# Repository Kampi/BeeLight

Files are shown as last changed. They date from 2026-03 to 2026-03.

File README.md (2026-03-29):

# BeeLight - Zigbee based light & environment sensor for Home Automation





## Table of Contents

- [BeeLight - Zigbee based light \& environment sensor for Home Automation](#beelight---zigbee-based-light--environment-sensor-for-home-automation)
  - [Table of Contents](#table-of-contents)
  - [About](#about)
    - [Technical features](#technical-features)
  - [Before you start](#before-you-start)
    - [PCB](#pcb)
    - [Firmware](#firmware)
      - [Build the firmware](#build-the-firmware)
      - [Flash the firmware](#flash-the-firmware)
      - [Generate the production config for the device](#generate-the-production-config-for-the-device)
        - [Using west](#using-west)
        - [Using the command line](#using-the-command-line)
    - [Housing](#housing)
    - [Zigbee](#zigbee)
      - [Standard clusters](#standard-clusters)
      - [Custom cluster](#custom-cluster)
      - [Zigbee Dongle](#zigbee-dongle)
      - [Install the device to Zigbee2MQTT](#install-the-device-to-zigbee2mqtt)
      - [Using the NCS Zigbee Shell](#using-the-ncs-zigbee-shell)
  - [Directory structure](#directory-structure)
  - [Resources](#resources)
  - [Maintainer](#maintainer)

## About

Open-Source Zigbee-based light and environmental sensor with [Zigbee2MQTT](https://www.zigbee2mqtt.io/) support for your Home Automation (e.g., Home Assistant).

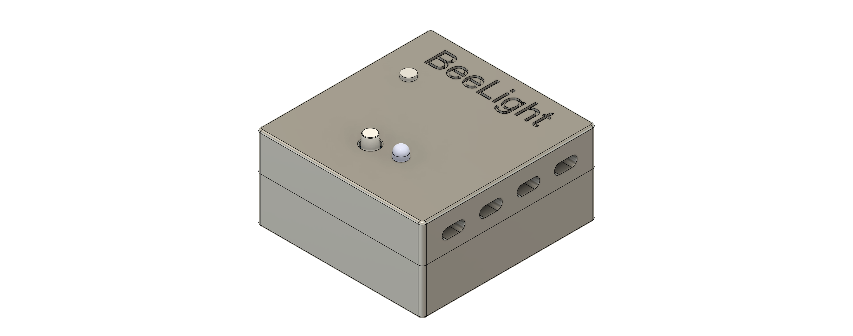
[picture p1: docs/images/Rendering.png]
Rendering


### Technical features

- Cutting-edge MCU module with an nRF54L, running Zephyr
- Powered by a single coin cell
- Can measure
  - Temperature
  - Humidity
  - Pressure
  - IAQ
  - CO2 equivalent
  - VOC equivalent
  - Light intensity
  - Battery voltage
- Small housing (40x42x20 mm)
- Very basic electronic → Can be assembled by hand very easily
- Zigbee2MQTT compatibility

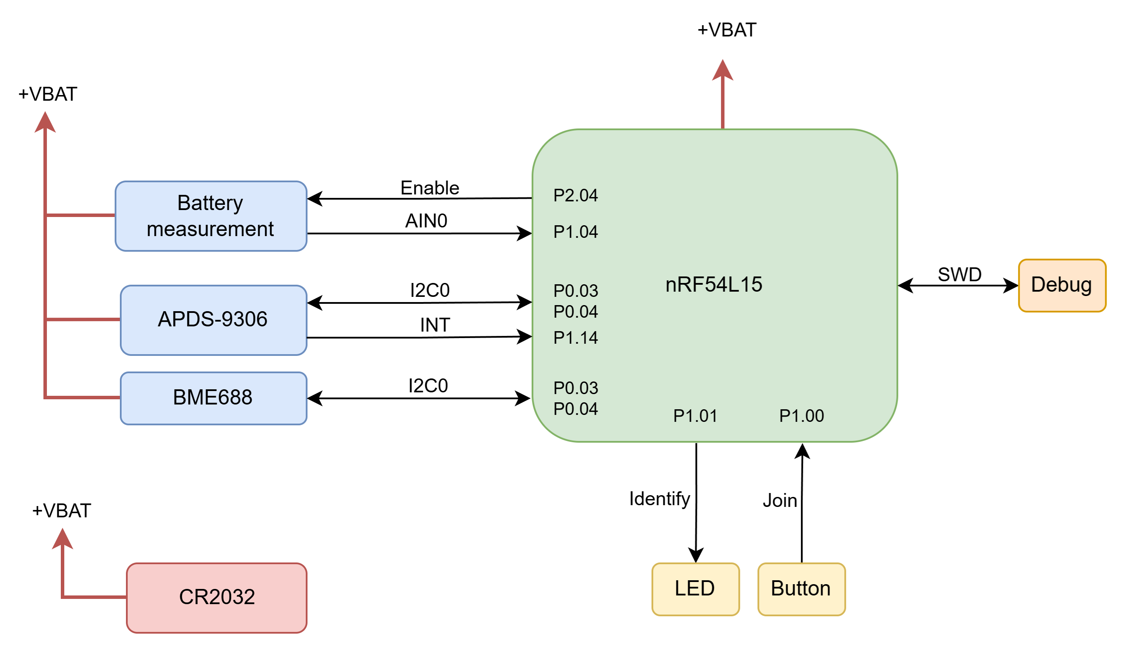
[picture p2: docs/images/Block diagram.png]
Block diagram


## Before you start

The project directory contains the hardware as a [KiCad 9](https://www.kicad.org/download/) project, the firmware and the Zigbee2MQTT configuration. You can check it out with Git:

```sh
git clone https://github.com/Kampi/BeeLight
cd BeeLight
git submodule update --init --recursive
cd firmware/app
west init -l .
west update
```

You also need [nrfutil](https://www.nordicsemi.com/Products/Development-tools/nRF-Util) and the `nrf5sdk-tools` to flash the production configuration to the sensor. First install `nrfutil` and then run the following command to install the SDK tools:

```sh
nrfutil install nrf5sdk-tools
```

### PCB

The project uses [Kibot](https://github.com/INTI-CMNB/KiBot) to automatically generate all required output data. After installing it you can execute the following command to run it:

```sh
cd hardware
./kibot-launch.sh
```

As an alternative you can run it via CI/CD in GitHub.

> **NOTE**
> You have to provide a Mouser API key with a variable called `MOUSER_KEY` to make use of the KiCost feature in the Kibot job.
>
> **NOTE**
> The programming connector is optional and can be left out or unsoldered after flashing the device.

### Firmware

#### Build the firmware

The firmware can be built with the following command:

```sh
cd firmware/app
west build --build-dir build . --pristine --board beelight@1/nrf54l15/cpuapp -- -DNCS_TOOLCHAIN_VERSION=NONE -DEXTRA_CONF_FILE=config/debug.conf -DBOARD_ROOT=.
```

You also need a Zigbee network to test and integrate the device. I use [Zigbee2MQTT](https://www.zigbee2mqtt.io/) running on a Raspberry Pi which allows me to connect my Zigbee network with my Home Automation.

> **NOTE**
> I do not support other Zigbee networks (like [ZHA](https://www.home-assistant.io/integrations/zha/)). The Zigbee standard allows you to connect the device with all other networks but I can't deliver a functional integration for these networks. You have to do it on your own!

#### Flash the firmware

After building the firmware you can run

```sh
west flash
```

to flash the firmware into the module.

> **NOTE**
> For some reason the current consumption stays high after flashing. I recommend a complete power cycle after flashing to make sure the device is consuming the lowest current possible.

#### Generate the production config for the device

##### Using west

You can run the command `west upload_config` to build and upload your configuration to the device automatically.

##### Using the command line

You must flash a production config to the device, before you can use it with Zigbee. You can either use the prebuilt config from the project or adjust it according to your needs.

```sh
nrfutil nrf5sdk-tools zigbee production_config zigbee_config.yml zigbee_config.hex --offset 0x17a000
nrfjprog --program zigbee_config.hex --verify
```

> **NOTE**
> The offset `0x17a000` is taken from the `PM_ZBOSS_PRODUCT_CONFIG_OFFSET` macro in `build/<app>/zephyr/include/generated/pm_config.h`. Also make sure to change `extended_address` in the Zigbee
> configuration file if you use more than one device!

### Housing

The housing is optimized for 3D printing and needs ~12 g of filament (PLA). You can find all the needed files in the `3d-printing` directory of this project.

### Zigbee

The device uses different standard and custom cluster to report the data to the network.

#### Standard clusters

| Cluster | ID |
| --- | -- |
| Temperature | 0x0402 |
| Pressure | 0x0403 |
| Rel. Humidity | 0x0405 |
| Light | 0x0400 |

#### Custom cluster

The device uses three custom cluster to report `IAQ`, `VOC` and `CO2` to the network. Both clusters have three attributes for `value`, `min_value`, `max_value` and `tolerance`.

| Cluster | ID |
| --- | -- |
| IAQ | 0x1A0A |
| VOC | 0x1A0B |
| CO2 | 0x1A0C |

| Attribute | ID |
| --- | -- |
| Value | 0x0000 |
| Min. Value | 0x0001 |
| Max. Value | 0x0002 |
| Tolerance | 0x0003 |

#### Zigbee Dongle

Make sure to use a Zigbee 3 compatible dongle like [SONOFF ZBDongle-E](https://sonoff.tech/product/gateway-and-sensors/sonoff-zigbee-3-0-usb-dongle-plus-e/) and update the firmware to the latest version to prevent issues. You can follow [this](https://dongle.sonoff.tech/sonoff-dongle-flasher/) guide if you use a SONOFF dongle.

#### Install the device to Zigbee2MQTT

> **NOTE**
> Because it's not possible to use custom clusters with Zigbee2MQTT easily, you must adjust the application directly to use the sensor. Please take a look into the directory `z2m/data/external_converters/example` if you want to check how the modified files look like.

1. Download and install [Zigbee2MQTT](https://github.com/zigbee2mqtt/hassio-zigbee2mqtt)
2. Copy the external converter from `z2m/data_external_converters` to the `data` directory of your `Zigbee2MQTT` installation
3. Switch into the directory `.../zigbee2mqtt/node_modules/zigbee-herdsman/dist/zspec/zcl/definition` and open `cluster.js` and add the following code to `exports.Clusters`

```ts
...
    msBeelightIAQ: {
        ID: 6666,
        attributes: {
            measuredValue: { ID: 0, type: enums_1.DataType.UINT16 },
            minMeasuredValue: { ID: 1, type: enums_1.DataType.UINT16 },
            maxMeasuredValue: { ID: 2, type: enums_1.DataType.UINT16 },
            tolerance: { ID: 3, type: enums_1.DataType.UINT8 },
        },
        commands: {},
        commandsResponse: {},
    },
    msBeelightVOC: {
        ID: 6667,
        attributes: {
            measuredValue: { ID: 0, type: enums_1.DataType.UINT16 },
            minMeasuredValue: { ID: 1, type: enums_1.DataType.UINT16 },
            maxMeasuredValue: { ID: 2, type: enums_1.DataType.UINT16 },
            tolerance: { ID: 3, type: enums_1.DataType.UINT8 },
        },
        commands: {},
        commandsResponse: {},
    },
    msBeelightCO2: {
        ID: 6668,
        attributes: {
            measuredValue: { ID: 0, type: enums_1.DataType.UINT16 },
            minMeasuredValue: { ID: 1, type: enums_1.DataType.UINT16 },
            maxMeasuredValue: { ID: 2, type: enums_1.DataType.UINT16 },
            tolerance: { ID: 3, type: enums_1.DataType.UINT8 },
        },
        commands: {},
        commandsResponse: {},
    },
...
```

4. Save the file
5. Switch to `.../zigbee2mqtt/node_modules/zigbee-herdsman-converters/dist/lib`
6. Open the file `modernExtend.js` and add the following cluster to the end of the list at the end of the file:
7. Add

```js
...
exports.BeeLight_iaq = BeeLight_iaq;
exports.BeeLight_co2 = BeeLight_co2;
exports.BeeLight_voc = BeeLight_voc;
...
```

8. Extend the following section

```js
// #region Measurement and Sensing
function BeeLight_iaq(args = {}) {
    return numeric({
        name: "BeeLight_iaq",
        cluster: "msBeelightIAQ",
        attribute: "measuredValue",
        reporting: { min: "5_MINUTES", max: "1_HOUR", change: 10 },
        description: "Measured IAQ value",
        unit: "",
        scale: 1,
        access: "STATE_GET",
        ...args,
    });
}
function BeeLight_co2(args = {}) {
    return numeric({
        name: "BeeLight_co2",
        cluster: "msBeelightCO2",
        attribute: "measuredValue",
        reporting: { min: "5_MINUTES", max: "1_HOUR", change: 10 },
        description: "Measured CO2 value",
        unit: "ppm",
        scale: 1,
        access: "STATE_GET",
        ...args,
    });
}
function BeeLight_voc(args = {}) {
    return numeric({
        name: "BeeLight_voc",
        cluster: "msBeelightVOC",
        attribute: "measuredValue",
        reporting: { min: "5_MINUTES", max: "1_HOUR", change: 10 },
        description: "Measured VOC value",
        unit: "ppm",
        scale: 1,
        access: "STATE_GET",
        ...args,
    });
}
...
```

9. Save the file
10. Restart Zigbee2MQTT

The device can now be connected to your Zigbee network and with this to your Home Assistant.

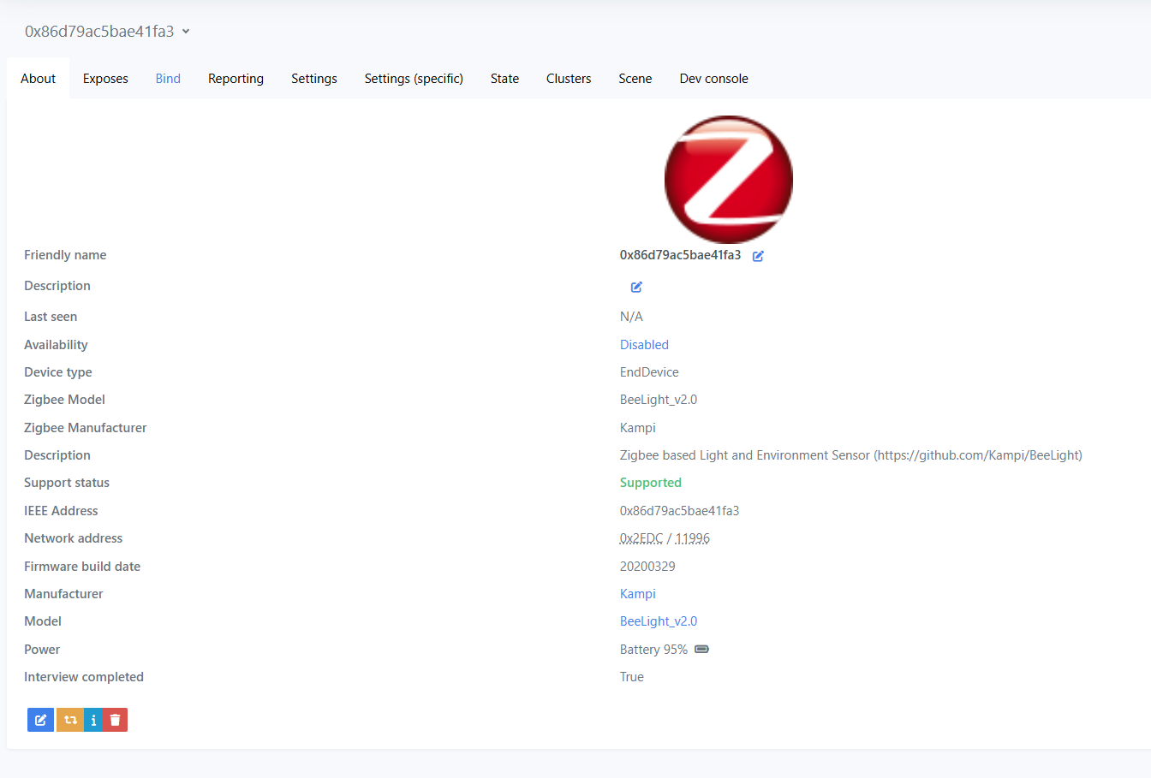
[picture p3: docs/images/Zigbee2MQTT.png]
Zigbee2MQTT

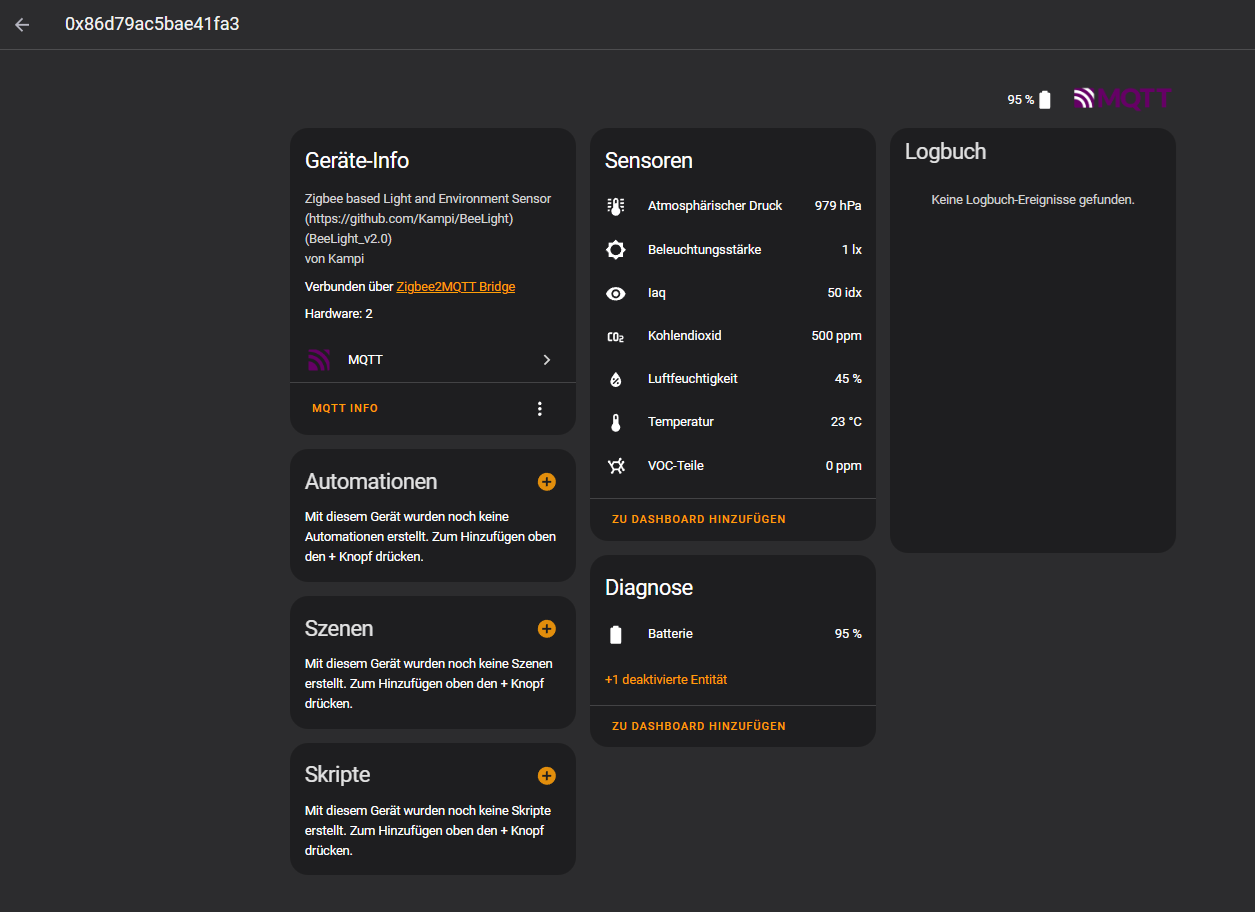
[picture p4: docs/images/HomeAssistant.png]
HomeAssistant


#### Using the NCS Zigbee Shell

You can test the device by using the NCS Zigbee Shell example and an nRF54DK or an nRF5340DK.

1. Flash the Zigbee Shell example to your board
2. Execute `nvram disable`
3. Execute `bdb role zc`
4. Execute `bdb channel 11`
5. Execute `bdb start`
6. Flash the sensor device firmware and the network configuration
7. Reset the sensor device and start the join procedure
8. You should get this output from the network coordinator device

```sh
[00:05:05.648,345] <inf> zigbee_app_utils: Joined network successfully (Extended PAN ID: f4ce36b2d4c06ca0, PAN ID: 0x6057)
[00:05:24.536,529] <inf> zigbee_app_utils: Device authorization event received (short: 0x02fa, long: 86d79ac5bae41fa3, authorization type: 3, authorization status: 0)
[00:05:24.536,773] <inf> zigbee_app_utils: Unimplemented signal (signal: 53, status: 0)
[00:05:24.537,139] <inf> zigbee_app_utils: Device update received (short: 0x02fa, long: 86d79ac5bae41fa3, status: 1)
```

9. Now you can read the clusters with `zcl attr read <Address> 10 <Cluster> 0x0104 0x0000`
10. Use `zcl subscribe on <Address> 10 <Cluster> 0x0104 0x00 33 <Min (s)> <Max (s)>` to create a binding for the given cluster

## Directory structure

- `3d-print`: All 3D print-related files
- `cad`: All relevant 3D models
- `docs`: All kinds of project documentation like schematics, BOM, etc.
  - `drawings`: 2D drawings for subcomponents, etc.
  - `images`: All documentation-relateBd images
- `hardware`: KiCad project for the PCB
- `firmware`: Zephyr project for the device firmware
- `prebuilt`: Prebuilt binaries
- `z2m`: Zigbee2MQTT-related files

## Resources

- [Adding new Zigbee2MQTT devices](https://www.zigbee2mqtt.io/advanced/support-new-devices/01_support_new_devices.html)
- [Zigbee Cluster Library Specification](https://zigbeealliance.org/wp-content/uploads/2019/12/07-5123-06-zigbee-cluster-library-specification.pdf)
- [Generating HEX files for Zigbee production configuration](https://docs.nordicsemi.com/bundle/nrfutil/page/nrfutil-nrf5sdk-tools/guides/generating_zigbee_hex.html)
- [Zigbee Converters](https://github.com/Koenkk/zigbee-herdsman-converters)
- [KiBot Template](https://github.com/nguyen-v/KDT_Hierarchical_KiBot)
- [Zigbee Shell](https://docs.nordicsemi.com/bundle/addon-zigbee-r23-latest/page/lib/shell.html#zdo_ieeeaddr)

## Maintainer

- [Daniel Kampert](mailto:DanielKampert@kampis-elektroecke.de)

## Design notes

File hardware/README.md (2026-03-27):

<p align="center" width="100%">
  
</p>

<h1 align="center">Template</h1>

<p align="center" width="100%">
  <a href="${GIT_URL}/actions/workflows/pcb.yaml">
    CI Badge
  </a>
</p>

***

<p align="center">
  3D Top Angled
&nbsp; &nbsp; &nbsp; &nbsp;
  3D Bottom Angled
</p>

***

## SPECIFICATIONS

| Parameter | Value |
| --- | --- |
| Dimensions | 32.0 × 24.0 mm |

***

## DIRECTORY STRUCTURE

    .
    ├─ Computations       # Misc calculations
    ├─ HTML               # HTML files for generated webpage
    ├─ Images             # Pictures and renders
    │
    ├─ kibot_resources    # External resources for KiBot
    │  ├─ colors          # Color theme for KiCad
    │  ├─ fonts           # Fonts used in the project
    │  ├─ scripts         # External scripts used with KiBot
    │  └─ templates       # Templates for KiBot generated reports
    │
    ├─ kibot_yaml         # KiBot YAML config files
    ├─ KiRI               # KiRI (PCB diff viewer) files
    │
    ├─ lib                # KiCad footprint and symbol libraries
    │  ├─ 3d_models       # Component 3D models
    │  ├─ lib_fp          # Footprint libraries
    │  └─ lib_sym         # Symbol libraries
    │
    ├─ Logos              # Logos
    │
    ├─ Manufacturing      # Assembly and fabrication documents
    │  ├─ Assembly        # Assembly documents (BoM, pos, notes)
    │  │
    │  └─ Fabrication     # Fabrication documents (ZIP, notes)
    │     ├─ Drill Tables # CSV drill tables
    │     └─ Gerbers      # Gerbers
    │
    ├─ Report             # Reports for ERC/DRC
    ├─ Schematic          # PDF of schematic
    ├─ Templates          # Title block templates
    ├─ Testing
    │  └─ Testpoints      # Testpoints tables
    │
    └─ Variants           # Outputs for assembly variants

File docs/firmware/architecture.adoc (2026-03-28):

= Software Architecture
Daniel Kampert <DanielKampert@kampis-elektroecke.de>
:description: BeeLight Firmware – Software Architecture
:doctype: book
:toc: left
:toclevels: 3
:icons: font
:source-highlighter: rouge
:imagesdir: ../images

== Overview

The BeeLight firmware is based on Zephyr RTOS and uses an event-driven design.
All communication between modules (sensors, Zigbee stack) is handled through the Zephyr ZBus message system.

image::Block diagram.png[Software Block Diagram, 600, align="center"]

== ZBus Event System

=== Concept

Zephyr ZBus is a message-based publish/subscribe bus that decouples modules.
In BeeLight, all sensor data and timer events are transmitted via ZBus channels.
A module publishes data on a channel; all registered listeners are automatically notified.

=== Channels

[cols="2,2,4", options="header"]
|===
| Channel | Message type | Description
| `periodic_5min_chan`  | `struct periodic_event`  | Timer tick every 5 minutes – triggers sensor measurements
| `periodic_24h_chan`   | `struct periodic_event`  | Timer tick every 24 hours – triggers battery measurement
| `light_data_chan`     | `struct light_event`      | Current illuminance in lux
| `env_data_chan`       | `struct env_event`        | Environmental data (temperature, pressure, humidity, optional CO₂/VOC/IAQ)
| `battery_data_chan`   | `struct battery_event`    | Battery voltage in millivolts
|===

=== Message Structures

.`struct light_event`
[source,c]
----
struct light_event {
    uint16_t light;   /* Illuminance in lux */
};
----

.`struct env_event`
[source,c]
----
struct env_event {
    float temperature;   /* Temperature in °C */
    float pressure;      /* Air pressure in Pa */
    float humidity;      /* Relative humidity in % */
#if CONFIG_BME68X_IAQ
    struct { float value; uint32_t tolerance; } iaq;  /* IAQ index */
    struct { float value; uint32_t tolerance; } voc;  /* VOC in ppm equivalent */
    struct { float value; uint32_t tolerance; } co2;  /* CO₂ equivalent in ppm */
#endif
};
----

.`struct battery_event`
[source,c]
----
struct battery_event {
    uint32_t voltage;   /* Voltage in millivolts */
    uint8_t  percent;   /* State of charge in percent */
};
----

== Periodic Timer System

Sensor measurements are not performed continuously but at fixed intervals to minimize power consumption.

The timer system implements two intervals as `k_work_delayable` objects:

[cols="1,2,4", options="header"]
|===
| Interval | Channel | Used by
| 5 minutes  | `periodic_5min_chan` | Light sensor (APDS-9306), environmental sensor (BME688)
| 24 hours   | `periodic_24h_chan`  | Battery voltage measurement (VBATT)
|===

After the Zigbee start signal (`ZB_ZDO_SIGNAL_SKIP_STARTUP`), the ZBus observers of the sensor modules are registered and the timer system starts.

== Module Overview

[cols="2,4", options="header"]
|===
| Module | Description
| `src/main.c`              | Application entry point, Zigbee initialization, ZBus callbacks for sensor channels
| `src/events/events.c`     | Definition of all ZBus channels and timer work queues
| `src/sensors/light.c`     | APDS-9306 light sensor – sampled every 5 minutes
| `src/sensors/environment.c` | BME688 environmental sensor – sampled every 5 minutes
| `src/sensors/battery.c`   | VBATT ADC measurement – sampled every 24 hours
| `src/beelight/beelight.h` | Zigbee cluster definitions, device context, macros
|===

== Zigbee ZBus Data Flow

----
periodic_5min_chan  ──►  light_periodic_sample_event_lis  ──►  APDS-9306  ──►  light_data_chan
                    ──►  env_periodic_sample_event_lis   ──►  BME688     ──►  env_data_chan

periodic_24h_chan   ──►  batt_periodic_sample_event_lis  ──►  VBATT ADC  ──►  battery_data_chan

light_data_chan     ──►  zbus_on_light_callback (main.c)   ──►  ZB_ZCL_SET_ATTRIBUTE (Illuminance)
env_data_chan       ──►  zbus_on_env_callback (main.c)     ──►  ZB_ZCL_SET_ATTRIBUTE (Temp/Press/Hum/CO2/IAQ/VOC)
battery_data_chan   ──►  zbus_on_battery_callback (main.c) ──►  ZB_ZCL_SET_ATTRIBUTE (Power Config)
----

== Power Consumption

The design is optimized for minimal power consumption:

* Zigbee End Device with configurable long-poll interval (default: 10 minutes)
* Sensor measurements only every 5 minutes or 24 hours respectively
* Unused RAM is powered down via `power_down_unused_ram()` (RAM Power Down Library)
* Sensor devices use `pm_device_runtime_get/put` for power management
* Zigbee aging timeout: 64 minutes (`ED_AGING_TIMEOUT_64MIN`)

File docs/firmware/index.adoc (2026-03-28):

= BeeLight Firmware
Daniel Kampert <DanielKampert@kampis-elektroecke.de>
:description: BeeLight Firmware – Project Overview
:doctype: book
:toc: left
:toclevels: 3
:icons: font
:source-highlighter: rouge
:imagesdir: ../images

== Overview

BeeLight is a battery-powered Zigbee environmental sensor based on the Nordic Semiconductor nRF54L15 SoC.
The device measures illuminance, temperature, air pressure, humidity, and battery voltage, and transmits all readings over a Zigbee network to a coordinator (e.g. Home Assistant via Zigbee2MQTT).

BeeLight 3D Rendering

=== Features

* *MCU*: Nordic Semiconductor nRF54L15 (ARM Cortex-M33, 128 MHz)
* *RTOS*: Zephyr RTOS with nRF Connect SDK 2.9.2
* *Protocol*: Zigbee 3.0 – Home Automation Profile (ZBOSS Stack via ncs-zigbee)
* *Sensors*:
** Broadcom APDS-9306 – Illuminance measurement
** Bosch BME688 – Temperature, air pressure, humidity
** Bosch BME688 (BSEC2, optional) – CO₂ equivalent, VOC, IAQ
* *Power supply*: CR2 battery (~3.3 V), voltage monitoring via ADC
* *Firmware version*: 2.0.0

=== Hardware Revisions

[cols="1,5", options="header"]
|===
| Revision | Description
| 0        | First BeeLight hardware revision
| 1        | Revised hardware revision
|===

== Integration

=== Home Assistant

The device registers itself automatically with Home Assistant as a sensor device after joining the Zigbee network.
All measured values are available as entities.

Home Assistant Integration

=== Zigbee2MQTT

The Zigbee2MQTT configuration is located in the `z2m/` directory of the repository.

Zigbee2MQTT Integration

== License

Copyright © 2025 Daniel Kampert. +
This project is licensed under the GNU General Public License v3.0.
For more information see https://www.gnu.org/licenses/.

== Further Documentation

* xref:architecture.adoc[Software Architecture]
* xref:sensors.adoc[Sensor Modules]
* xref:zigbee.adoc[Zigbee Integration]
* xref:build.adoc[Build & Configuration]

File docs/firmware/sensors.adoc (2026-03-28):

= Sensor Modules
Daniel Kampert <DanielKampert@kampis-elektroecke.de>
:description: BeeLight Firmware – Sensor Modules
:doctype: book
:toc: left
:toclevels: 3
:icons: font
:source-highlighter: rouge
:imagesdir: ../images

== Overview

The BeeLight firmware implements three sensor modules, each registered as standalone initialization modules via Zephyr SYS_INIT.
Each module subscribes to a periodic ZBus channel and publishes its measurement data on a dedicated data channel.

[cols="3,2,2,4", options="header"]
|===
| Module | Sensor | Measurement interval | Zigbee cluster
| `src/sensors/light.c`       | APDS-9306 | 5 minutes  | Illuminance Measurement
| `src/sensors/environment.c` | BME688    | 5 minutes  | Temperature, Pressure, Humidity (+ CO₂/VOC/IAQ optional)
| `src/sensors/battery.c`     | VBATT ADC | 24 hours   | Power Configuration
|===

== Light Sensor – APDS-9306

=== Hardware

The Broadcom APDS-9306 is a digital ambient light sensor (ALS) with I²C interface.
It measures illuminance in lux and is referenced in the device tree under the label `apds9306`.

NOTE: The APDS-9306 driver is integrated into the build via Zephyr patches from `patches/zephyr/`.

=== Operation

The module subscribes to `periodic_5min_chan` and performs a measurement on each tick:

[source,c]
----
sensor_sample_fetch(apds9306);
sensor_channel_get(apds9306, SENSOR_CHAN_LIGHT, &sensor_val);
evt.light = sensor_val.val1;
zbus_chan_pub(&light_data_chan, &evt, K_NO_WAIT);
----

The raw sensor output (lux) is converted to the logarithmic Zigbee Illuminance value in `main.c`:

[source,c]
----
zb_uint16_t measured = (evt->light == 0)
    ? 0
    : (zb_uint16_t)(10000 * log10((double)evt->light) + 1);
----

=== Debug-Modus

Bei aktiviertem `CONFIG_DEBUG` und nicht vorhandenem Sensor werden synthetische Testdaten
(inkrementierender Zähler) auf `light_data_chan` veröffentlicht.

=== Konfiguration

[cols="2,4", options="header"]
|===
| Kconfig option | Description
| `CONFIG_APDS9306` | Enables the APDS-9306 driver (provided via Zephyr patch)
|===

== Environmental Sensor – BME688

=== Hardware

The Bosch BME688 is an integrated gas sensor with I²C interface, measuring temperature, air pressure,
relative humidity, and gas resistance (for VOC/IAQ/CO₂ equivalent).
The sensor is referenced in the device tree under the label `bme688`.

=== Operating Modes

==== Basic Mode (without BSEC2)

Temperature, air pressure, and humidity are measured:

[cols="2,3", options="header"]
|===
| Zephyr channel | Measurement
| `SENSOR_CHAN_AMBIENT_TEMP` | Temperature in °C
| `SENSOR_CHAN_PRESS`        | Air pressure in Pa
| `SENSOR_CHAN_HUMIDITY`     | Relative humidity in %
|===

==== IAQ Mode (with BSEC2)

When `CONFIG_BME68X_IAQ` is enabled, the following channels are additionally evaluated:

[cols="2,3", options="header"]
|===
| Zephyr channel | Measurement
| `SENSOR_CHAN_CO2`  | CO₂ equivalent in ppm
| `SENSOR_CHAN_VOC`  | VOC in ppm equivalent
| `SENSOR_CHAN_IAQ`  | IAQ index (0–500)
|===

Each BSEC2 value also includes a `tolerance` value indicating the measurement accuracy/reliability.

=== Measurement Sequence

[source,c]
----
sensor_sample_fetch(bme688);
sensor_channel_get(bme688, SENSOR_CHAN_AMBIENT_TEMP, &sensor_val);
evt.temperature = sensor_val.val1;
// ... further channels
zbus_chan_pub(&env_data_chan, &evt, K_NO_WAIT);
----

=== Konfiguration

[cols="2,4", options="header"]
|===
| Kconfig option | Description
| `CONFIG_BME68X_IAQ` | Enables BSEC2 integration for CO₂, VOC, and IAQ measurement
|===

== Battery Monitoring – VBATT

=== Hardware

The battery voltage is measured via an ADC voltage divider.
The Zephyr device is defined in the device tree under the label `vbatt` as a `voltage-divider` sensor.

=== Measurement Chain

The measurement is taken every 24 hours:

[source,c]
----
pm_device_runtime_get(vbatt);
sensor_sample_fetch(vbatt);
sensor_channel_get(vbatt, SENSOR_CHAN_VOLTAGE, &sensor_val);
evt.voltage = (sensor_val.val1 * 1000) + (sensor_val.val2 / 1000);  /* in mV */
pm_device_runtime_put(vbatt);
----

=== State of Charge Calculation

The percentage charge level is linearly interpolated between the configured voltage limits:

[source,c]
----
#define BEELIGHT_RATED_VOLTAGE_MV   3300UL   /* 100 % */
#define BEELIGHT_EMPTY_VOLTAGE_MV   2700UL   /*   0 % */
----

[source,c]
----
int32_t remaining = (evt->voltage - BEELIGHT_EMPTY_VOLTAGE_MV);
remaining = (remaining * 100) / (BEELIGHT_RATED_VOLTAGE_MV - BEELIGHT_EMPTY_VOLTAGE_MV);
dev_ctx.power_attr.percent_remaining = remaining * 2;  /* Zigbee: 200 = 100 % */
----

NOTE: In the Zigbee Power Configuration Cluster, a `BatteryPercentageRemaining` value of 200 represents full charge (100 %).

=== Voltage-to-ZCL Conversion

The battery voltage is scaled to the ZCL unit (100 mV per unit) by integer division by 100:

[source,c]
----
dev_ctx.power_attr.voltage = evt->voltage / 100;
----

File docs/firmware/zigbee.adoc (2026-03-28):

= Zigbee Integration
Daniel Kampert <DanielKampert@kampis-elektroecke.de>
:description: BeeLight Firmware – Zigbee Integration
:doctype: book
:toc: left
:toclevels: 3
:icons: font
:source-highlighter: rouge
:imagesdir: ../images

== Overview

BeeLight implements a Zigbee 3.0 End Device in the Home Automation Profile.
The ZBOSS stack is integrated via the ncs-zigbee module.
All measurement values are provided as ZCL attributes on Endpoint 10 and can be queried by the Zigbee coordinator or received as reports.

== Device Profile

[cols="2,3", options="header"]
|===
| Parameter | Value
| Zigbee profile     | Home Automation (`ZB_AF_HA_PROFILE_ID`)
| Device ID          | `0x0106`
| Endpoint           | 10
| Firmware version   | 2.0.0
| Manufacturer name  | `Kampi`
| Model ID           | `BeeLight_v2`
|===

== Endpoint Configuration

=== Server Clusters (IN)

[cols="2,3,3", options="header"]
|===
| Cluster ID | Name | Description
| `0x0000` | Basic                    | Device information (version, manufacturer, model)
| `0x0003` | Identify                 | Identify mode (LED blinking via button)
| `0x0001` | Power Configuration      | Battery voltage and state of charge
| `0x0400` | Illuminance Measurement  | Illuminance in lux (logarithmic)
| `0x0402` | Temperature Measurement  | Temperature in 0.01 °C
| `0x0403` | Pressure Measurement     | Air pressure in 0.1 hPa
| `0x0405` | Relative Humidity Measurement | Relative humidity in 0.01 %
| `0x1A0C` | CO₂ Measurement (BeeLight) | CO₂ equivalent in ppm (optional, BSEC2)
| `0x1A0A` | IAQ Measurement (BeeLight) | IAQ index 0–500 (optional, BSEC2)
| `0x1A0B` | VOC Measurement (BeeLight) | VOC in ppm equivalent (optional, BSEC2)
|===

=== Client Clusters (OUT)

[cols="2,3,3", options="header"]
|===
| Cluster ID | Name | Description
| `0x0003` | Identify (Client) | Binding support for Identify responses
|===

== ZCL Attributes

=== Basic Cluster (0x0000)

[cols="2,2,3", options="header"]
|===
| Attribute | Type | Value
| `ZCLVersion`           | uint8  | `ZB_ZCL_VERSION`
| `ApplicationVersion`   | uint8  | 1
| `StackVersion`         | uint8  | 10
| `HWVersion`            | uint8  | Board revision (from `CONFIG_BOARD_REVISION`)
| `ManufacturerName`     | string | `"Kampi"`
| `ModelIdentifier`      | string | `"BeeLight_v2"`
| `DateCode`             | string | `"20251019_Debug"` / `"20251019_Release"`
| `PowerSource`          | enum8  | Battery (`0x03`)
| `LocationDescription`  | string | `"Office desk"`
| `PhysicalEnvironment`  | enum8  | Unspecified
| `SWBuildID`            | string | Git commit hash (generated automatically)
|===

=== Power Configuration Cluster (0x0001)

[cols="2,2,3", options="header"]
|===
| Attribute | Type | Description
| `BatteryVoltage`              | uint8 | Battery voltage in 100 mV units
| `BatteryPercentageRemaining`  | uint8 | State of charge (200 = 100 %)
| `BatterySize`                 | enum8 | CR2 (`0x06`)
| `BatteryQuantity`             | uint8 | 1
| `BatteryRatedVoltage`         | uint8 | 33 (3300 mV / 100)
|===

=== Illuminance Measurement Cluster (0x0400)

[cols="2,2,3", options="header"]
|===
| Attribute | Type | Description
| `MeasuredValue`    | uint16 | Illuminance: `10000 × log10(Lux) + 1`
| `MinMeasuredValue` | uint16 | Minimum of measured values
| `MaxMeasuredValue` | uint16 | Maximum of measured values
|===

=== Temperature Measurement Cluster (0x0402)

[cols="2,2,3", options="header"]
|===
| Attribute | Type | Description
| `MeasuredValue`    | int16  | Temperature × 100 (e.g. 2150 = 21.5 °C)
| `MinMeasuredValue` | int16  | Minimum of measured values
| `MaxMeasuredValue` | int16  | Maximum of measured values
| `Tolerance`        | uint16 | Measurement uncertainty
|===

=== Pressure Measurement Cluster (0x0403)

[cols="2,2,3", options="header"]
|===
| Attribute | Type | Description
| `MeasuredValue`    | int16  | Air pressure in 0.1 hPa (e.g. 10132 = 1013.2 hPa)
| `MinMeasuredValue` | int16  | Minimum of measured values
| `MaxMeasuredValue` | int16  | Maximum of measured values
| `Tolerance`        | uint16 | Measurement uncertainty
|===

=== Relative Humidity Measurement Cluster (0x0405)

[cols="2,2,3", options="header"]
|===
| Attribute | Type | Description
| `MeasuredValue`    | uint16 | Humidity × 100 (e.g. 5500 = 55.00 %)
| `MinMeasuredValue` | uint16 | Minimum of measured values
| `MaxMeasuredValue` | uint16 | Maximum of measured values
|===

== BeeLight Custom Clusters

The following three clusters are BeeLight-specific extensions.
They are integrated into the ZBOSS stack via the patch `patches/ncs-zigbee/0001-Add-BeeLight-specific-clusters.patch`.

NOTE: The custom clusters are only available when `CONFIG_BME68X_IAQ=y` is set.

=== CO₂ Measurement (0x1A0C)

[cols="2,2,3", options="header"]
|===
| Attribute ID | Type | Description
| `0x0000` (`VALUE_ID`)     | uint16 | CO₂ equivalent in ppm
| `0x0001` (`MIN_VALUE_ID`) | uint16 | MinMeasuredValue (0x8000 = invalid)
| `0x0002` (`MAX_VALUE_ID`) | uint16 | MaxMeasuredValue (0x8000 = invalid)
| `0x0003` (`TOLERANCE_ID`) | uint8  | BSEC2 algorithm accuracy level
|===

Value range `MeasuredValue`: 0–400 ppm (max `0x0190`). +
Unknown value: `0x8000`.

=== IAQ Measurement (0x1A0A)

[cols="2,2,3", options="header"]
|===
| Attribute ID | Type | Description
| `0x0000` (`VALUE_ID`)     | uint16 | IAQ index (0 = very good, 500 = extremely poor)
| `0x0001` (`MIN_VALUE_ID`) | uint16 | MinMeasuredValue (0x8000 = invalid)
| `0x0002` (`MAX_VALUE_ID`) | uint16 | MaxMeasuredValue (0x8000 = invalid)
| `0x0003` (`TOLERANCE_ID`) | uint8  | BSEC2 algorithm accuracy level
|===

Initialization: Min and Max are set to `0x8000` (invalid). +
Value range `MeasuredValue`: 0–500 (max `0x01F4`).

=== VOC Measurement (0x1A0B)

[cols="2,2,3", options="header"]
|===
| Attribute ID | Type | Description
| `0x0000` (`VALUE_ID`)     | uint16 | VOC in ppm equivalent
| `0x0001` (`MIN_VALUE_ID`) | uint16 | MinMeasuredValue (0x8000 = invalid)
| `0x0002` (`MAX_VALUE_ID`) | uint16 | MaxMeasuredValue (0x8000 = invalid)
| `0x0003` (`TOLERANCE_ID`) | uint8  | BSEC2 algorithm accuracy level
|===

Value range `MeasuredValue`: 0–10000 (max `0x2710`).

== Identify Mode

The Identify mode is controlled via Button 1 (DK_BTN1):

* Short press → Start Identify mode (binding target)
* Long press → Factory reset

In Identify mode, LED 1 (`ZIGBEE_NETWORK_STATE_LED`) blinks at 100 ms intervals.

== Zigbee Network Behavior

[cols="2,4", options="header"]
|===
| Parameter | Value / Behavior
| Device role               | End Device (no router, no coordinator)
| ED aging timeout          | 64 minutes
| Keepalive interval        | 1 minute
| Long poll interval        | 10 minutes
| Network LED (join)        | 4× blink on successful join
| Network LED (leave)       | 2× blink on leaving the network
|===

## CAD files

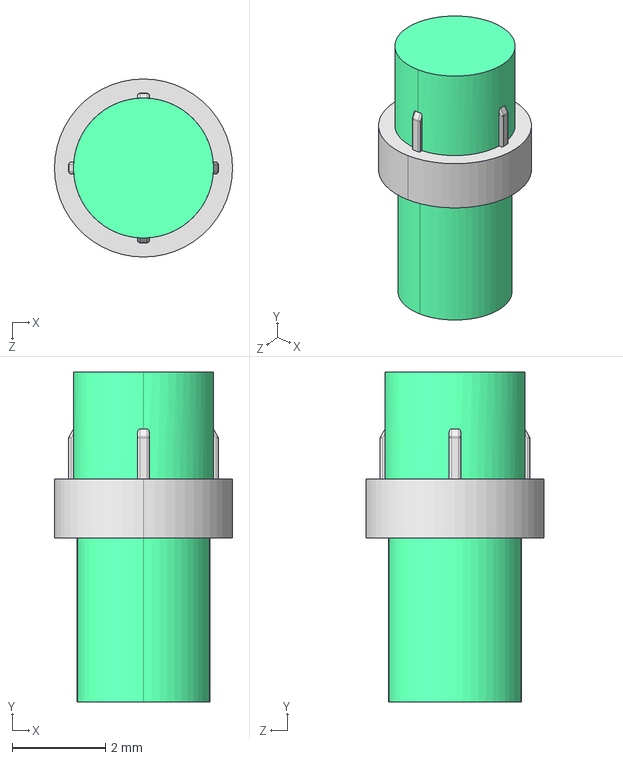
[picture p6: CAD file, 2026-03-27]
cad/BIVAR__INC_PLP1-188-F.stp
3.81 x 7.06 x 3.81 mm

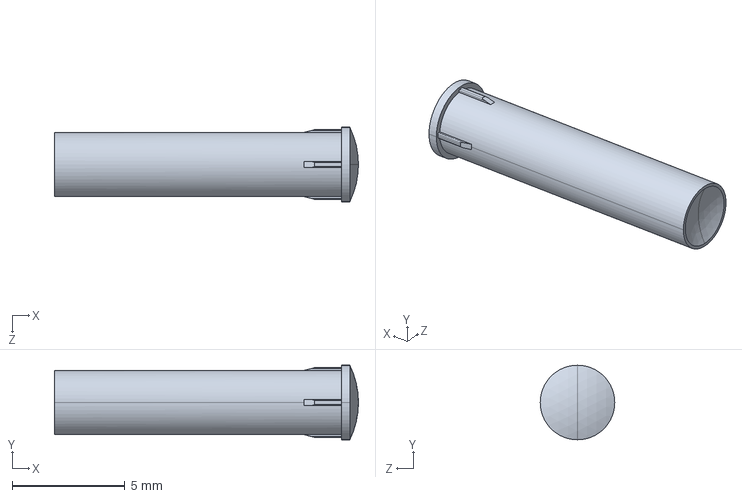
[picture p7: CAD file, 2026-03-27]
cad/LFB012CTP.stp
13.5 x 3.30 x 3.30 mm

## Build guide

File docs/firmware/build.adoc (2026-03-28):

= Build & Configuration
Daniel Kampert <DanielKampert@kampis-elektroecke.de>
:description: BeeLight Firmware – Build & Configuration
:doctype: book
:toc: left
:toclevels: 3
:icons: font
:source-highlighter: rouge

== Prerequisites

=== Toolchain

[cols="2,3", options="header"]
|===
| Tool | Version / Source
| nRF Connect SDK    | 2.9.2
| Zephyr SDK         | 0.17.0
| west               | >= 1.2.0
| CMake              | >= 3.20.0
| Python             | >= 3.8
|===

=== west Initialization

[source,bash]
----
# Create workspace directory
mkdir beelight_workspace && cd beelight_workspace

# Clone repository
git clone https://github.com/Kampi/BeeLight BeeLight

# Initialize west
cd BeeLight/firmware/app
west init -l .

# Enable BSEC2 module (for IAQ support)
west config manifest.group-filter +bsec2

# Download dependencies
west update
----

NOTE: Without `+bsec2` in the group-filter configuration, `CONFIG_BME68X_IAQ` is not available.

== Board Support

The BeeLight board is defined as a custom board under `boards/kampi/beelight/`.
The build must specify `--board-root .` (relative to the `app/` directory).

=== Supported Boards

[cols="2,2,4", options="header"]
|===
| Board qualifier | Revision | Description
| `beelight/nrf54l15/cpuapp` | 0 | Hardware revision 0 (`beelight@0`)
| `beelight/nrf54l15/cpuapp` | 1 | Hardware revision 1 (`beelight@1`)
|===

=== Board Files

[source]
----
boards/kampi/beelight/
+-- beelight_nrf54l15_cpuapp.dts
+-- beelight_nrf54l15_cpuapp_defconfig
+-- beelight_nrf54l15_cpuapp_0.overlay
+-- beelight_nrf54l15_cpuapp_0_defconfig
+-- beelight_nrf54l15_cpuapp_1.overlay
+-- beelight_nrf54l15_cpuapp_1_defconfig
----

== Build Commands

=== Debug Build

[source,bash]
----
cd BeeLight/firmware/app
west build \
    --build-dir beelight@0_nrf54l15_cpuapp_debug \
    --pristine \
    --board beelight@0/nrf54l15/cpuapp \
    -- \
    -DNCS_TOOLCHAIN_VERSION=NONE \
    -DCONF_FILE="config/debug.conf" \
    -DBOARD_ROOT=.
----

=== Release Build

[source,bash]
----
cd BeeLight/firmware/app
west build \
    --build-dir beelight@0_nrf54l15_cpuapp_release \
    --pristine \
    --board beelight@0/nrf54l15/cpuapp \
    -- \
    -DNCS_TOOLCHAIN_VERSION=NONE \
    -DCONF_FILE="config/release.conf" \
    -DBOARD_ROOT=.
----

=== Flashing

[source,bash]
----
west flash --build-dir beelight@0_nrf54l15_cpuapp_debug
----

== Configuration Variants

=== config/debug.conf

[source,kconfig]
----
CONFIG_DEBUG=y
CONFIG_LOG=y
CONFIG_LOG_PRINTK=y
CONFIG_DEBUG_INFO=y
CONFIG_DEBUG_OPTIMIZATIONS=y
CONFIG_USE_SEGGER_RTT=y
CONFIG_LOG_BACKEND_RTT=y
CONFIG_LOG_BACKEND_RTT_MODE_BLOCK=y
CONFIG_LOG_BUFFER_SIZE=4096
----

* Logging via Segger RTT enabled
* Debug optimizations (-Og) and debug information
* In debug mode, synthetic test data is generated when no sensor is present

=== config/release.conf

[source,kconfig]
----
CONFIG_DEBUG=n
CONFIG_LOG=y
CONFIG_LOG_PRINTK=y
----

* Debug symbol disabled – no synthetic sensor fallback

== Important Kconfig Options

[cols="3,1,4", options="header"]
|===
| Option | Default | Description
| `CONFIG_BME68X_IAQ`             | n | Enables BSEC2 integration (CO2, VOC, IAQ). Requires +bsec2 west group.
| `CONFIG_APDS9306`               | y | Enables the APDS-9306 light sensor driver (via Zephyr patch)
| `CONFIG_DEBUG`                  | n | Debug mode (synthetic sensor data, debug logging)
| `CONFIG_RAM_POWER_DOWN_LIBRARY` | y | Power down unused RAM banks at startup
| `CONFIG_ZIGBEE_FOTA`            | n | OTA firmware update (not yet supported)
|===

== Patch System

The firmware uses a two-stage patch mechanism that is executed during the CMake configuration step.

=== Zephyr Patches (`patches/zephyr/`)

[cols="3,4", options="header"]
|===
| Patch | Description
| `0001-...APDS-9306.patch`       | APDS-9306 driver implementation
| `0003-...return-value.patch`    | Bugfix: unchecked return values
| `0004-...reset.patch`           | Removes reset sequence from driver
| `0005-...lux-conversion.patch`  | Lux conversion in driver
|===

=== ncs-zigbee Patches (`patches/ncs-zigbee/`)

[cols="3,4", options="header"]
|===
| Patch | Description
| `0001-Add-BeeLight-specific-clusters.patch` | Adds CO₂, IAQ, and VOC clusters (0x1A0A–0x1A0C) to ZBOSS
|===

IMPORTANT: In the CI/CD pipeline, the ncs-zigbee patch is applied explicitly as a separate pipeline step
before the build, since it cannot be reliably found in the CMake context.

== Build Artifacts

After a successful build, the firmware image is located at:

[source]
----
<build-dir>/merged.hex          # Complete hex image (app + bootloader)
<build-dir>/zephyr/merged.hex   # Alternative path (depending on bootloader configuration)
----

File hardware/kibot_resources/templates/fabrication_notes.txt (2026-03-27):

FABRICATION NOTES (UNLESS OTHERWISE SPECIFIED)

1)	FABRICATE PER IPC-6012A CLASS 2.

2)	OUTLINE DEFINED IN SEPARATE GERBER FILE WITH
	"Edge_Cuts.GBR" SUFFIX.

	DIMENSIONS OF CIRCUMSIZED RECTANGLE SHOWN ON THIS
	DRAWING FOR REFERENCE ONLY.

3)	SEE SEPARATE DRILL FILES WITH ".DRL" SUFFIX 
	FOR HOLE LOCATIONS.

	SELECTED HOLE LOCATIONS SHOWN ON THIS DRAWING 
	FOR REFERENCE ONLY.

4)	SURFACE FINISH: ${pcb_finish_cap}

5)	SOLDERMASK ON BOTH SIDES OF THE BOARD SHALL 
	BE LPI, COLOR ${solder_mask_color_text_cap}.

6)	SILK SCREEN LEGEND TO BE APPLIED PER LAYER 
	STACKUP USING ${silk_screen_color_text_cap} NON-CONDUCTIVE EPOXY INK.

7)	ALL VIAS ARE TENTED ON BOTH SIDES UNLESS 
	SOLDERMASK OPENED IN GERBER.

8)	VENDOR SHOULD FOLLOW ROHS COMPLIANT PROCESS 
	AND Pb FREE FOR MANUFACTURING

9)	PCB MATERIAL REQUIREMENTS:

	A.	FLAMMABILITY RATING MUST MEET OR EXCEED 
		UL94V-0 REQUIREMENTS.
	B.	Tg 150 C OR EQUIVALENT.
	C.	EQUIVALENT MATERIAL SHALL BE RoHS COMPLIANT, 
		HALOGEN FREE AND APPROVED BY ${COMPANY_cap}.

10)	DESIGN GEOMETRY MINIMUM FEATURE SIZES:

	BOARD SIZE				${bb_w_mm} × ${bb_h_mm} mm
	BOARD THICKNESS		${thickness_mm} mm
	TRACE WIDTH			${track_mm} mm
	TRACE TO TRACE		${clearance_mm} mm
	MIN. HOLE (PTH)			${drill_pth_real_mm} mm
	MIN. HOLE (NPTH)		${drill_npth_real_mm} mm
	ANNULAR RING			${oar_mm} mm
	COPPER TO HOLE		${c2h_mm} mm
	COPPER TO EDGE		${c2e_mm} mm
	HOLE TO HOLE			${h2h_mm} mm
#?stackup and impedance_controlled

#?stackup and impedance_controlled
11)	REFER TO IMPEDANCE TABLE FOR IMPEDANCE CONTROL REQUIREMENTS.
#?stackup and impedance_controlled

#?stackup and impedance_controlled
12)	CONFIRM SPACE WIDTHS AND SPACINGS.

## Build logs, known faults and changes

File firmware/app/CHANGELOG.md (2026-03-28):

# CHANGELOG

## [2.1] - 28.03.2026

**Changed:**

- Switch to nRF SDK Connect SDK (NCS) v3
- Switch to ZBOSS R23
- Switch to Z2M 2.6.3

**Added:**

- Add BME688
- Add support for BME688 only and Bosch BSEC
- Add blocklist to west manifest
- Add groupfilters to west manifest
- Add west command to build and flash the device configuration
- Add custom cluster for VOC, IAQ and CO2 for Zigbee2MQTT
- Add patches for custom cluster for ncs-zigbee

## [1.0] - 12.01.2024

- Initial release

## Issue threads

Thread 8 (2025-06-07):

Measure current consumption

Kampi, 2025-06-07:
**Setup**
- No SWD connected (leakage through the debugger)
- No BME688 soldered
- No APDS soldered
- Series resistor for LED removed because the IO isn´t completely disabled in the samples

**Results**
- Current on my board with system_off  sample from Zephyr: avg. 1.6 uA
- Current on my board with system_off  sample from Zephyr and system_off replaced with k_sleep(K_FOREVER): avg. 4 uA

- Current on my board with system_off in my firmware: avg. 0.61 uA
- Current on my board with k_sleep in my firmware: avg. 150 uA

Looks like something in my firmware is keeping the current consumption high.

Closed 2025-06-27.

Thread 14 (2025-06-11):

PCB image is missing in README after running CI/CD for KiCad

Kampi, 2025-06-11:

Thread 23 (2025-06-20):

Create device tree for revision 2

Kampi, 2025-06-20:
Revision 2 of the PCB should fix the wrong I2C pins, so soft-I2C isn´t necessary anymore.

Closed 2025-06-28.

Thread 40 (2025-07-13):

KiBot PCB output is not correct

Kampi, 2025-07-13:

Closed 2025-09-09.

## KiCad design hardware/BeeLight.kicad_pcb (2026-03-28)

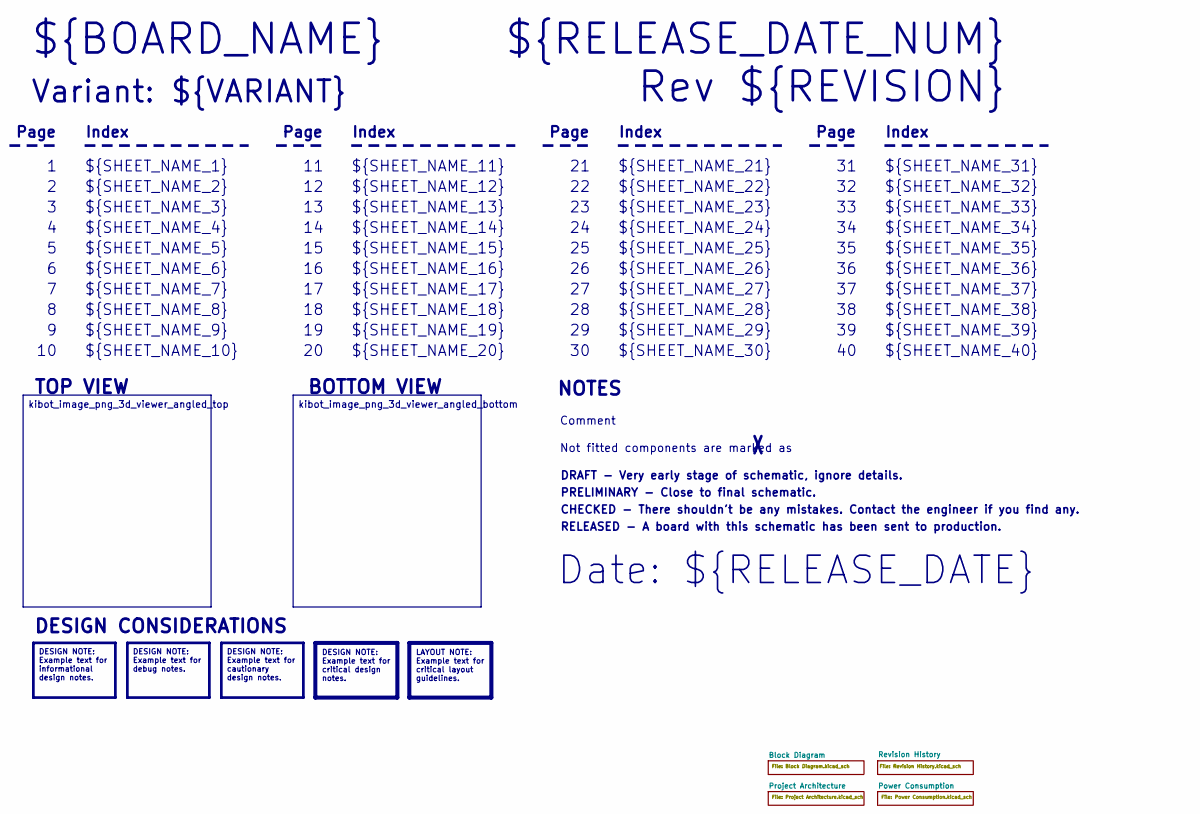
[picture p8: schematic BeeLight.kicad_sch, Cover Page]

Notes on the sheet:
Variant: ${VARIANT}
RELEASED - A board with this schematic has been sent to production.
${SHEET_NAME_24}
Index
Page
PRELIMINARY - Close to final schematic.
${SHEET_NAME_22}
DRAFT - Very early stage of schematic, ignore details.
${SHEET_NAME_12}
${SHEET_NAME_8}
${SHEET_NAME_2}
${SHEET_NAME_5}
${SHEET_NAME_20}
${SHEET_NAME_23}
${RELEASE_DATE_NUM}
${SHEET_NAME_35}
Not fitted components are marked as
${SHEET_NAME_11}
${SHEET_NAME_6}
${SHEET_NAME_37}
${SHEET_NAME_26}
${SHEET_NAME_36}
Rev ${REVISION}
${SHEET_NAME_15}
CHECKED - There shouldn't be any mistakes. Contact the engineer if you find any.
BOTTOM VIEW
${SHEET_NAME_14}
${SHEET_NAME_21}
${SHEET_NAME_17}
${SHEET_NAME_18}
Date: ${RELEASE_DATE}
${SHEET_NAME_7}
${SHEET_NAME_31}
${BOARD_NAME}
NOTES
${SHEET_NAME_40}
${SHEET_NAME_39}
${SHEET_NAME_32}
${SHEET_NAME_1}
${SHEET_NAME_9}


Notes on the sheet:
${RELEASE_BODY_1.1.0}
[${#}] ${TITLE}
${RELEASE_BODY_1.0.0}
${RELEASE_TITLE_1.0.2}
${RELEASE_BODY_1.0.2}
${RELEASE_BODY_1.0.1}
${RELEASE_TITLE_1.0.0}
${RELEASE_TITLE_1.0.1}
${RELEASE_TITLE_1.1.0}

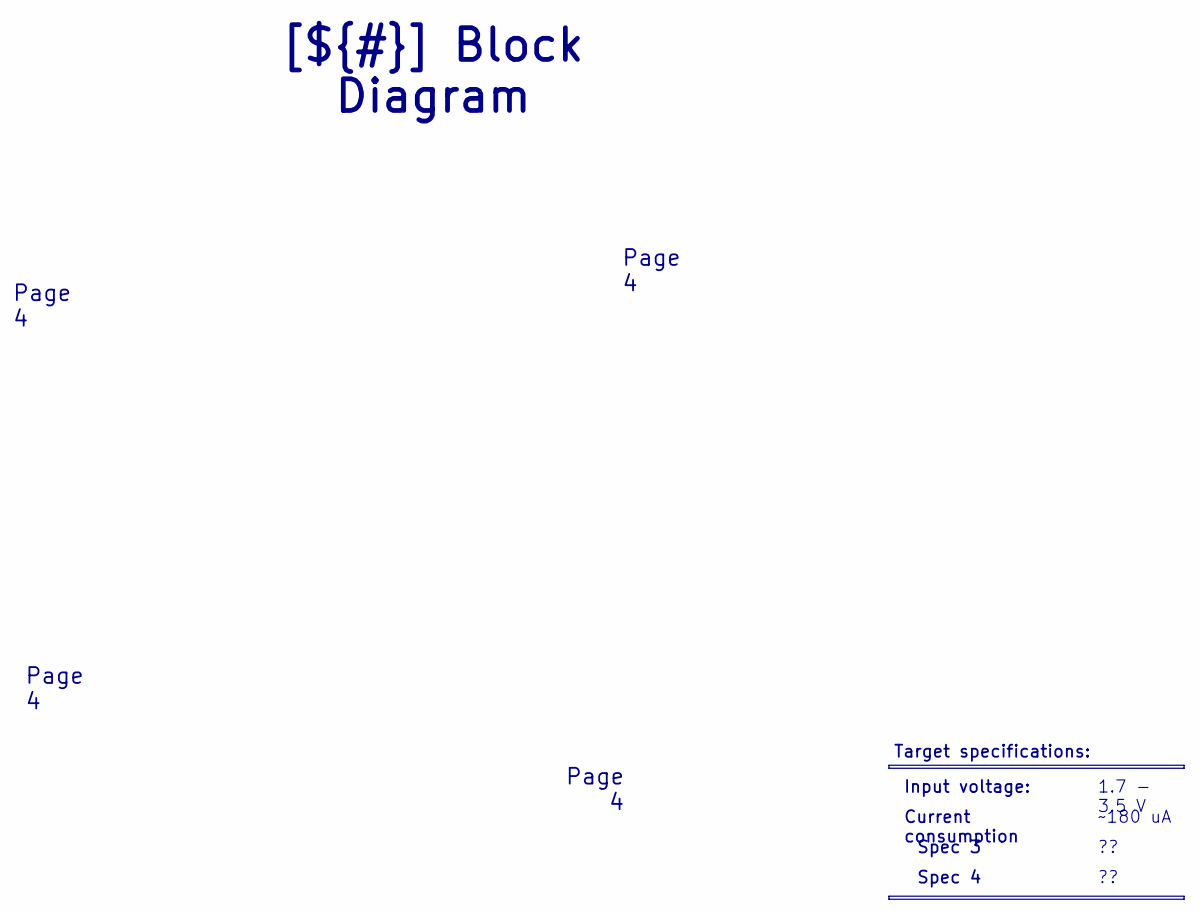
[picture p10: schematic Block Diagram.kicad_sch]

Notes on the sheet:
Spec 4
1.7 - 3.5 V
Page 4
[${#}] ${TITLE}
~180 uA
Input voltage:
Target specifications:
Spec 3
Current consumption

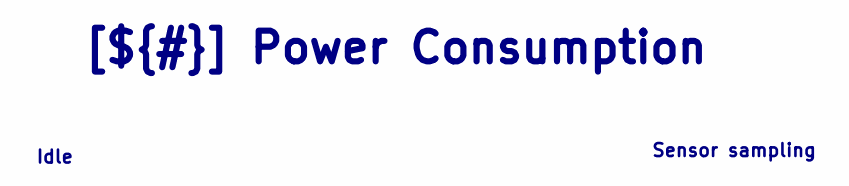
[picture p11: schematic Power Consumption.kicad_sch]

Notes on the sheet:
Sensor sampling
[${#}] ${TITLE}
Idle

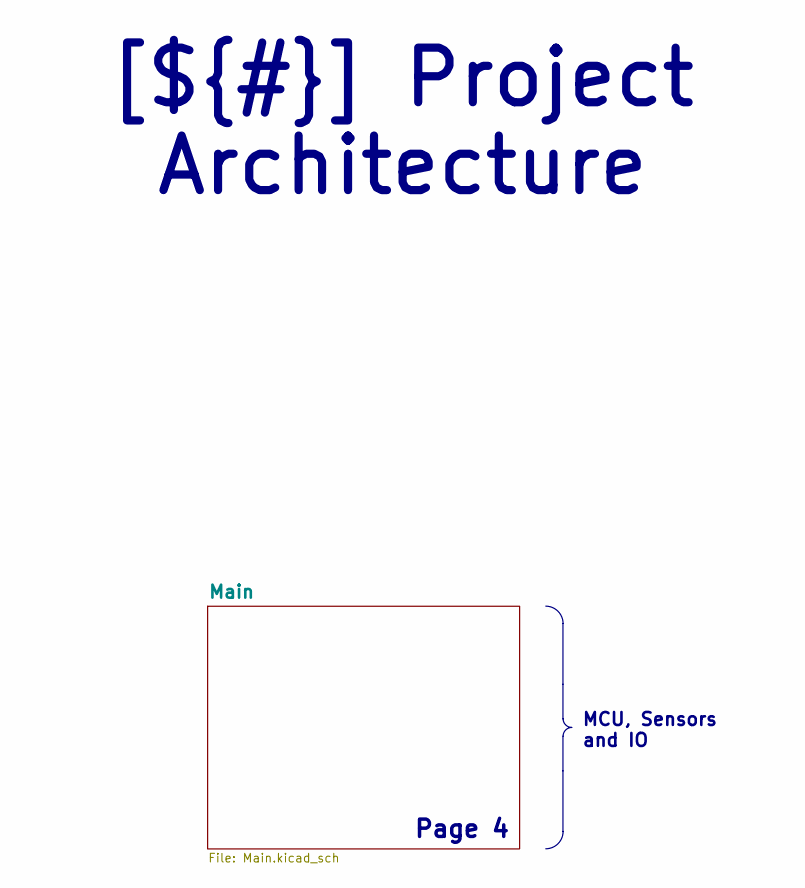
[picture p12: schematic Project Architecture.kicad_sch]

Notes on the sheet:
Page 4
MCU, Sensors and IO
[${#}] ${TITLE}

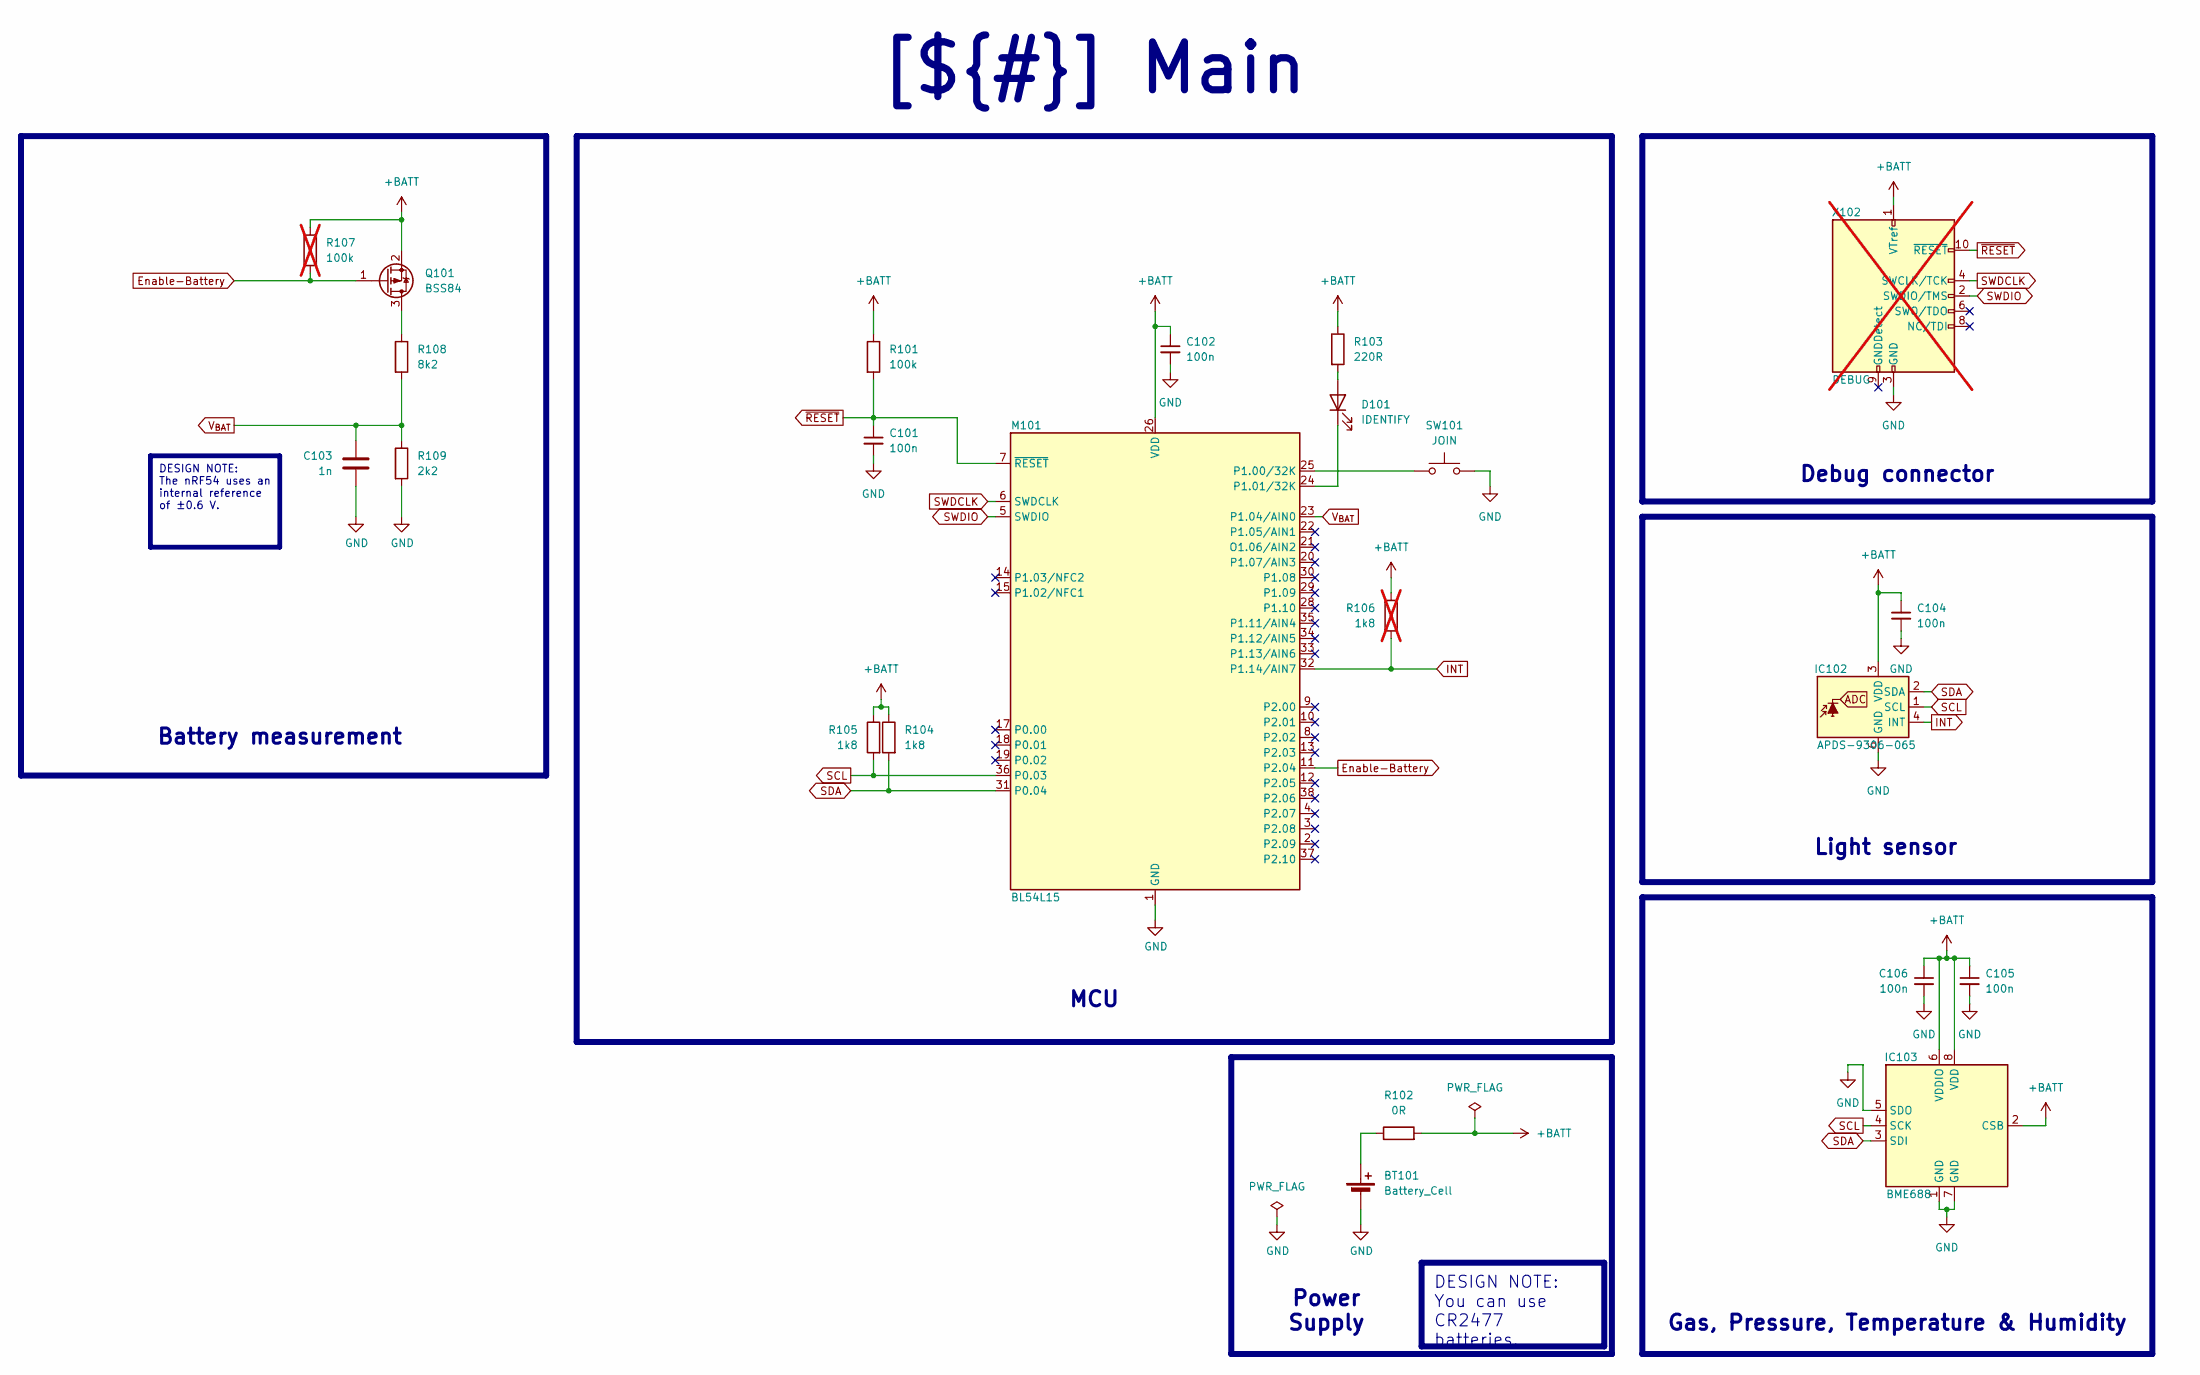
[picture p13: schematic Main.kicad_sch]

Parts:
BT101: Battery_Cell; 3039; mouser# 534-3039
C101, C102, C104, C105, C106: 100n; C_0402_1005Metric_Pad0.74x0.62mm_HandSolder; mouser# 581-04025C104KAT4A
C103: 1n; C_0402_1005Metric_Pad0.74x0.62mm_HandSolder; mouser# 81-GCM1555C2A102JE02D
D101: IDENTIFY; LED_0805_2012Metric_Pad1.15x1.40mm_HandSolder; mouser# 630-HSMQ-C170-T0000
IC102: APDS-9306-065; Broadcom_DFN-6_2x2mm_P0.65mm; mouser# 630-APDS-9306-065
IC103: BME688; Bosch_LGA-8_3x3mm_P0.8mm_ClockwisePinNumbering; mouser# 262-BME688
M101: BL54L15; mouser# 239-453-00001C
Q101: BSS84; SOT-23-3; mouser# 512-BSS84
R101: 100k; R_0402_1005Metric_Pad0.72x0.64mm_HandSolder; mouser# 603-RC0402FR-07100KL
R102: 0R; R_0805_2012Metric_Pad1.20x1.40mm_HandSolder; mouser# 652-CR0805AJ/-000EAS
R103: 220R; R_0402_1005Metric_Pad0.72x0.64mm_HandSolder; mouser# 652-CR0402-JW-221GLF
R104, R105: 1k8; R_0402_1005Metric_Pad0.72x0.64mm_HandSolder; mouser# 603-RC0402FR-071K8L
R106: 1k8; R_0402_1005Metric_Pad0.72x0.64mm_HandSolder; mouser# 603-RC0402FR-071K8L; not fitted
R107: 100k; R_0402_1005Metric_Pad0.72x0.64mm_HandSolder; mouser# 603-RC0402FR-07100KL; not fitted
R108: 8k2; R_0402_1005Metric_Pad0.72x0.64mm_HandSolder; mouser# 603-RT0402BRD078K2L
R109: 2k2; R_0402_1005Metric_Pad0.72x0.64mm_HandSolder; mouser# 603-RT0402BRD072K2L
SW101: JOIN; WS-TASV-6x6; mouser# 710-430182095816
X102: DEBUG; PinHeader_2x05_P1.27mm_Vertical; mouser# 200-SHF-105-01-L-D-TH-TR; not fitted

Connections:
+BATT: C102.1, C104.1, C105.1, C106.1, IC102.3 (VDD), IC103.2 (CSB), IC103.6 (VDDIO), IC103.8 (VDD), M101.26 (VDD), Q101.2 (S), R101.1, R102.2, R103.1, R104.1, R105.1, R106.1, R107.1, X102.1 (VTref)
Enable-Battery: M101.11 (P2.04), Q101.1 (G), R107.2
GND: BT101.2 (-), C101.2, C102.2, C103.2, C104.2, C105.2, C106.2, IC102.6 (GND), IC103.1 (GND), IC103.5 (SDO), IC103.7 (GND), M101.1 (GND), M101.16 (GND), M101.27 (GND), M101.39 (GND), R109.2, SW101.1, X102.3 (GND), X102.5 (GND)
INT: IC102.4 (INT), M101.32 (P1.14/AIN7), R106.2
unnamed: BT101.1 (+), R102.1
unnamed: D101.2 (A), R103.2
unnamed: D101.1 (K), M101.24 (P1.01/32K)
unnamed: M101.25 (P1.00/32K), SW101.2
unnamed: Q101.3 (D), R108.1
SCL: IC102.1 (SCL), IC103.4 (SCK), M101.36 (P0.03), R105.2
SDA: IC102.2 (SDA), IC103.3 (SDI), M101.31 (P0.04), R104.2
SWDCLK: M101.6 (SWDCLK), X102.4 (SWCLK/TCK)
SWDIO: M101.5 (SWDIO), X102.2 (SWDIO/TMS)
V_{BAT}: C103.1, M101.23 (P1.04/AIN0), R108.2, R109.1
~RESET: C101.1, M101.7 (~RESET), R101.2, X102.10 (~RESET)

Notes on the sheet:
DESIGN NOTE: You can use CR2477 batteries.
[${#}] ${TITLE}
Power Supply
Battery measurement
MCU
Light sensor
Debug connector
DESIGN NOTE: The nRF54 uses an internal reference of ±0.6 V.
Gas, Pressure, Temperature & Humidity

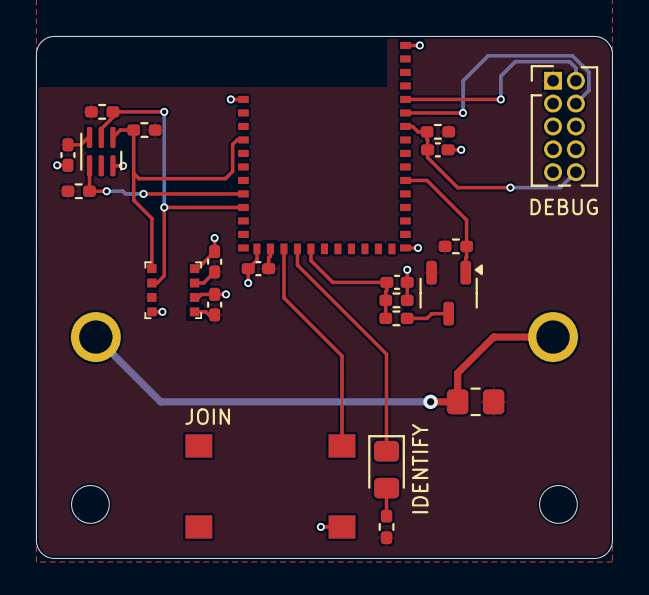
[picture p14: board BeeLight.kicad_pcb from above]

Board: 2 copper layers, 32.0 x 29.0 mm, 23 parts (1 on the bottom side), 15 nets.

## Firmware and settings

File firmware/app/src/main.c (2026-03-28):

/*
 * This file is part of the BeeLight project <https://github.com/Kampi/BeeLight>.
 * Copyright (c) 2026 Daniel Kampert.
 *
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
 * You should have received a copy of the GNU General Public License
 * along with this program. If not, see <http://www.gnu.org/licenses/>.
 */

#include <zephyr/types.h>
#include <zephyr/kernel.h>
#include <zephyr/device.h>
#include <zephyr/logging/log.h>
#include <zephyr/settings/settings.h>

#include <soc.h>
#include <ram_pwrdn.h>
#include <dk_buttons_and_leds.h>

#include <zboss_api.h>
#include <zboss_api_addons.h>
#include <zb_nrf_platform.h>
#include <zb_mem_config_med.h>
#include <zigbee/zigbee_app_utils.h>
#include <zigbee/zigbee_error_handler.h>

#include <math.h>
#include <stdlib.h>

#include "events.h"
#include "beelight/beelight.h"

/** @brief Zigbee device application context storage.
 */
static device_ctx_t dev_ctx;

/** @brief
 */
static void zbus_on_light_callback(const struct zbus_channel *chan);

/** @brief
 */
static void zbus_on_env_callback(const struct zbus_channel *chan);

/** @brief
 */
static void zbus_on_battery_callback(const struct zbus_channel *chan);

/* Declare attribute list for Identify cluster (client). */
ZB_ZCL_DECLARE_IDENTIFY_CLIENT_ATTRIB_LIST(
    identify_client_attr_list);

/** @brief Declare attribute list for Identify cluster (server).
 */
ZB_ZCL_DECLARE_IDENTIFY_SERVER_ATTRIB_LIST(
    identify_server_attr_list,
    &dev_ctx.identify_attr.identify_time);

/** @brief
 */
ZB_ZCL_DECLARE_BASIC_ATTRIB_LIST_EXT(
    basic_attr_list,
    &dev_ctx.basic_attr.zcl_version,
    &dev_ctx.basic_attr.app_version,
    &dev_ctx.basic_attr.stack_version,
    &dev_ctx.basic_attr.hw_version,
    dev_ctx.basic_attr.mf_name,
    dev_ctx.basic_attr.model_id,
    dev_ctx.basic_attr.date_code,
    &dev_ctx.basic_attr.power_source,
    dev_ctx.basic_attr.location_id,
    &dev_ctx.basic_attr.ph_env,
    dev_ctx.basic_attr.sw_ver);

/** @brief Power cluster attributes additions data.
 */
ZB_ZCL_DECLARE_POWER_CONFIG_BATTERY_ATTRIB_LIST_EXT(
    power_attr_list,
    &dev_ctx.power_attr.voltage,
    &dev_ctx.power_attr.size,
    &dev_ctx.power_attr.quantity,
    &dev_ctx.power_attr.rated_voltage,
    &dev_ctx.power_attr.alarm_mask,
    &dev_ctx.power_attr.voltage_min_threshold,
    &dev_ctx.power_attr.percent_remaining,
    &dev_ctx.power_attr.voltage_threshold_1,
    &dev_ctx.power_attr.voltage_threshold_2,
    &dev_ctx.power_attr.voltage_threshold_3,
    &dev_ctx.power_attr.percent_min_threshold,
    &dev_ctx.power_attr.percent_threshold_1,
    &dev_ctx.power_attr.percent_threshold_2,
    &dev_ctx.power_attr.percent_threshold_3,
    &dev_ctx.power_attr.alarm_state);

/** @brief Illuminance cluster attributes additions data.
 */
ZB_ZCL_DECLARE_ILLUMINANCE_MEASUREMENT_ATTRIB_LIST(
    light_sensor_attr_list,
    &dev_ctx.illuminance_attr.measurement_attr,
    &dev_ctx.illuminance_attr.min_attr,
    &dev_ctx.illuminance_attr.max_attr);

/** @brief Temperature cluster attributes additions data.
 */
ZB_ZCL_DECLARE_TEMP_MEASUREMENT_ATTRIB_LIST(
    temp_sensor_attr_list,
    &dev_ctx.temperature_attr.measurement_attr,
    &dev_ctx.temperature_attr.min_attr,
    &dev_ctx.temperature_attr.max_attr,
    &dev_ctx.temperature_attr.tolerance);

/** @brief Pressure cluster attributes additions data.
 */
ZB_ZCL_DECLARE_PRESSURE_MEASUREMENT_ATTRIB_LIST(
    pres_sensor_attr_list,
    &dev_ctx.pressure_attr.measurement_attr,
    &dev_ctx.pressure_attr.min_attr,
    &dev_ctx.pressure_attr.max_attr,
    &dev_ctx.pressure_attr.tolerance);

/** @brief Humidity cluster attributes additions data.
 */
ZB_ZCL_DECLARE_REL_HUMIDITY_MEASUREMENT_ATTRIB_LIST(
    hum_sensor_attr_list,
    &dev_ctx.humidity_attr.measurement_attr,
    &dev_ctx.humidity_attr.min_attr,
    &dev_ctx.humidity_attr.max_attr);

#if CONFIG_BME68X_IAQ
/** @brief Carbon Dioxide cluster attributes additions data.
 */
ZB_BEELIGHT_DECLARE_CO2_MEASUREMENT_ATTRIB_LIST(
    co2_sensor_attr_list,
    &dev_ctx.co2_attr.measurement_attr,
    &dev_ctx.co2_attr.min_attr,
    &dev_ctx.co2_attr.max_attr,
    &dev_ctx.co2_attr.tolerance);

/** @brief IAQ cluster attributes additions data.
 */
ZB_BEELIGHT_DECLARE_IAQ_MEASUREMENT_ATTRIB_LIST(
    iaq_sensor_attr_list,
    &dev_ctx.iaq_attr.measurement_attr,
    &dev_ctx.iaq_attr.min_attr,
    &dev_ctx.iaq_attr.max_attr,
    &dev_ctx.iaq_attr.tolerance);

/** @brief VOC cluster attributes additions data.
 */
ZB_BEELIGHT_DECLARE_VOC_MEASUREMENT_ATTRIB_LIST(
    voc_sensor_attr_list,
    &dev_ctx.voc_attr.measurement_attr,
    &dev_ctx.voc_attr.min_attr,
    &dev_ctx.voc_attr.max_attr,
    &dev_ctx.voc_attr.tolerance);
#endif /* CONFIG_BME68X_IAQ */

BEELIGHT_DECLARE_CLUSTER_LIST(
    env_sensor_clusters,
    basic_attr_list,
    identify_client_attr_list,
    identify_server_attr_list,
    power_attr_list,
    light_sensor_attr_list,
    temp_sensor_attr_list,
    pres_sensor_attr_list,
#if CONFIG_BME68X_IAQ
    hum_sensor_attr_list,
    co2_sensor_attr_list,
    iaq_sensor_attr_list,
    voc_sensor_attr_list
#else
    hum_sensor_attr_list
#endif /* CONFIG_BME68X_IAQ */
);

BEELIGHT_DECLARE_EP(
    env_sensor_ep,
    BEELIGHT_ENDPOINT,
    env_sensor_clusters);

ZBOSS_DECLARE_DEVICE_CTX_1_EP(
    env_sensor_ctx,
    env_sensor_ep);

ZBUS_CHAN_DECLARE(light_data_chan);
ZBUS_LISTENER_DEFINE(light_data_lis, zbus_on_light_callback);

ZBUS_CHAN_DECLARE(env_data_chan);
ZBUS_LISTENER_DEFINE(env_data_lis, zbus_on_env_callback);

ZBUS_CHAN_DECLARE(battery_data_chan);
ZBUS_LISTENER_DEFINE(battery_data_lis, zbus_on_battery_callback);

LOG_MODULE_REGISTER(app, LOG_LEVEL_DBG);

/** @brief          Function to toggle the identify LED.
 *  @param bufid    Unused parameter, required by ZBOSS scheduler API
 */
static void toggle_identify_led(zb_bufid_t bufid)
{
    ZB_SCHEDULE_APP_ALARM(toggle_identify_led, bufid, ZB_MILLISECONDS_TO_BEACON_INTERVAL(100));
}

/** @brief          Starts identifying the device.
 *  @param bufid    Unused parameter, required by ZBOSS scheduler API
 */
static void start_identifying(zb_bufid_t bufid)
{
    ZVUNUSED(bufid);

    if (ZB_JOINED()) {
        /* Check if endpoint is in identifying mode, if not, put desired endpoint in identifying mode. */
        if (dev_ctx.identify_attr.identify_time == ZB_ZCL_IDENTIFY_IDENTIFY_TIME_DEFAULT_VALUE) {

            zb_ret_t zb_err_code = zb_bdb_finding_binding_target(BEELIGHT_ENDPOINT);

            if (zb_err_code == RET_OK) {
                LOG_INF("Enter identify mode");
            } else if (zb_err_code == RET_INVALID_STATE) {
                LOG_WRN("RET_INVALID_STATE - Cannot enter identify mode");
            } else {
                ZB_ERROR_CHECK(zb_err_code);
            }
        } else {
            LOG_INF("Cancel identify mode");
            zb_bdb_finding_binding_target_cancel();
        }
    } else {
        LOG_WRN("Device not in a network - cannot enter identify mode");
    }
}

static void on_Identify_Handler(zb_bufid_t bufid)
{
    zb_ret_t err = RET_OK;

    if (bufid) {
        /* Schedule a self-scheduling function that will toggle the LED */
        err = ZB_SCHEDULE_APP_CALLBACK(toggle_identify_led, bufid);
        if (err) {
            LOG_ERR("Failed to schedule app callback: %d", err);
        } else {
            LOG_INF("Enter identify mode");
        }
    } else {
        /* Cancel the toggling function alarm and turn off LED */
        err = ZB_SCHEDULE_APP_ALARM_CANCEL(toggle_identify_led,
                                           ZB_ALARM_ANY_PARAM);
        if (err) {
            LOG_ERR("Failed to schedule app alarm cancel: %d", err);
        } else {
            dk_set_led_off(ZIGBEE_NETWORK_STATE_LED);
            LOG_INF("Cancel identify mode");
        }
    }
}

/** @brief              Callback for button events.
 *  @param button_state Bitmask containing the state of the buttons
 *  @param has_changed  Bitmask containing buttons that have changed their state
 */
static void on_button_changed_handler(uint32_t button_state, uint32_t has_changed)
{
    LOG_DBG("Button pressed");

    if (IDENTIFY_MODE_BUTTON & has_changed) {
        if (IDENTIFY_MODE_BUTTON & button_state) {
        }
        /* Button changed its state to pressed */
        else {
            /* Button changed its state to released */
            if (was_factory_reset_done()) {
                /* The long press was for Factory Reset */
                LOG_DBG("After Factory Reset - ignore button release");
            }
            /* Button released before Factory Reset */
            else {
                LOG_DBG("Start identifying");

                /* Start identification mode */
                ZB_SCHEDULE_APP_CALLBACK(start_identifying, 0);
            }
        }
    }

    check_factory_reset_button(button_state, has_changed);
}

/** @brief Function for initializing all clusters attributes.
 */
static void app_clusters_attr_init(void)
{
    /* Basic cluster attributes data */
    dev_ctx.basic_attr.zcl_version = ZB_ZCL_VERSION;
    dev_ctx.basic_attr.app_version = INIT_BASIC_APP_VERSION;
    dev_ctx.basic_attr.stack_version = INIT_BASIC_STACK_VERSION;

#ifdef CONFIG_BOARD_REVISION
    dev_ctx.basic_attr.hw_version = (zb_uint8_t)atoi(CONFIG_BOARD_REVISION);
#else
    dev_ctx.basic_attr.hw_version = INIT_BASIC_HW_VERSION;
#endif /* CONFIG_BOARD_REVISION */

    /* Use ZB_ZCL_SET_STRING_VAL to set strings, because the first byte */
    /* should contain string length without trailing zero. */
    /* For example "test" string will be encoded as: */
    /*   [(0x4), 't', 'e', 's', 't'] */
    ZB_ZCL_SET_STRING_VAL(
        dev_ctx.basic_attr.mf_name,
        INIT_BASIC_MANUF_NAME,
        ZB_ZCL_STRING_CONST_SIZE(INIT_BASIC_MANUF_NAME)
    );

    ZB_ZCL_SET_STRING_VAL(
        dev_ctx.basic_attr.model_id,
        INIT_BASIC_MODEL_ID,
        ZB_ZCL_STRING_CONST_SIZE(INIT_BASIC_MODEL_ID)
    );

    ZB_ZCL_SET_STRING_VAL(
        dev_ctx.basic_attr.date_code,
        INIT_BASIC_DATE_CODE,
        ZB_ZCL_STRING_CONST_SIZE(INIT_BASIC_DATE_CODE)
    );

    dev_ctx.basic_attr.power_source = ZB_ZCL_BASIC_POWER_SOURCE_BATTERY;

    ZB_ZCL_SET_STRING_VAL(
        dev_ctx.basic_attr.location_id,
        INIT_BASIC_LOCATION_DESC,
        ZB_ZCL_STRING_CONST_SIZE(INIT_BASIC_LOCATION_DESC)
    );

    dev_ctx.basic_attr.ph_env = ZB_ZCL_BASIC_ENV_UNSPECIFIED;

    /* Identify cluster attributes data. */
    dev_ctx.identify_attr.identify_time = ZB_ZCL_IDENTIFY_IDENTIFY_TIME_DEFAULT_VALUE;

#if CONFIG_BME68X_IAQ
    /* Initialize IAQ/VOC/CO2 min and max with their INVALID sentinels so that
     * check_value_iaq_measurement_server does not reject measured values > 0. */
    dev_ctx.iaq_attr.min_attr = ZB_BEELIGHT_ATTR_IAQ_MEASUREMENT_MIN_VALUE_INVALID;
    dev_ctx.iaq_attr.max_attr = ZB_BEELIGHT_ATTR_IAQ_MEASUREMENT_MAX_VALUE_INVALID;
#endif /* CONFIG_BME68X_IAQ */

    /* Initialize the values for the Battery cluster attributes */
    dev_ctx.power_attr.size = ZB_ZCL_POWER_CONFIG_BATTERY_SIZE_CR2;
    dev_ctx.power_attr.quantity = 1;
    dev_ctx.power_attr.rated_voltage = BEELIGHT_RATED_VOLTAGE_MV / 100;

    ZB_ZCL_SET_ATTRIBUTE(
        BEELIGHT_ENDPOINT,
        ZB_ZCL_CLUSTER_ID_POWER_CONFIG,
        ZB_ZCL_CLUSTER_SERVER_ROLE,
        ZB_ZCL_ATTR_POWER_CONFIG_BATTERY_VOLTAGE_ID,
        (zb_uint8_t *)&dev_ctx.power_attr.voltage,
        ZB_FALSE
    );

    ZB_ZCL_SET_ATTRIBUTE(
        BEELIGHT_ENDPOINT,
        ZB_ZCL_CLUSTER_ID_POWER_CONFIG,
        ZB_ZCL_CLUSTER_SERVER_ROLE,
        ZB_ZCL_ATTR_POWER_CONFIG_BATTERY_PERCENTAGE_REMAINING_ID,
        (zb_uint8_t *)&dev_ctx.power_attr.percent_remaining,
        ZB_FALSE
    );
}

/** @brief          Callback function for handling ZCL commands.
 *  @param bufid    Reference to Zigbee stack buffer used to pass received data
 */
static void on_zcl_cb_handler(zb_bufid_t bufid)
{
    zb_zcl_device_callback_param_t *device_cb_param = ZB_BUF_GET_PARAM(bufid, zb_zcl_device_callback_param_t);

    if (device_cb_param->device_cb_id == ZB_ZCL_OTA_UPGRADE_VALUE_CB_ID) {
#ifdef CONFIG_ZIGBEE_FOTA
        zigbee_fota_zcl_cb(bufid);
#endif /* CONFIG_ZIGBEE_FOTA */
    } else {
        device_cb_param->status = RET_NOT_IMPLEMENTED;
    }
}

/** @brief          Zigbee stack event handler.
 *  @param bufid    Reference to the Zigbee stack buffer used to pass signal
 */
void zboss_signal_handler(zb_bufid_t bufid)
{
    zb_zdo_app_signal_hdr_t *p_sg_p = NULL;
    zb_zdo_app_signal_type_t sig = zb_get_app_signal(bufid, &p_sg_p);
    zb_ret_t status = ZB_GET_APP_SIGNAL_STATUS(bufid);

    /* Update network status LED. */
    switch (sig) {
        case ZB_SIGNAL_JOIN_DONE: {
            dk_set_led_off(ZIGBEE_NETWORK_STATE_LED);
            if (status == RET_OK) {
                for (uint8_t i = 0; i < 4; i++) {
                    dk_set_led_on(ZIGBEE_NETWORK_STATE_LED);
                    k_msleep(100);
                    dk_set_led_off(ZIGBEE_NETWORK_STATE_LED);
                    k_msleep(100);
                }
            }

            break;
        }
        case ZB_ZDO_SIGNAL_LEAVE: {
            for (uint8_t i = 0; i < 2; i++) {
                dk_set_led_on(ZIGBEE_NETWORK_STATE_LED);
                k_msleep(100);
                dk_set_led_off(ZIGBEE_NETWORK_STATE_LED);
                k_msleep(100);
            }

            break;
        }
        case ZB_ZDO_SIGNAL_SKIP_STARTUP: {
            LOG_DBG("Add observers for sensors");
            zbus_chan_add_obs(&battery_data_chan, &battery_data_lis, K_MSEC(100));
            zbus_chan_add_obs(&light_data_chan, &light_data_lis, K_MSEC(100));
            zbus_chan_add_obs(&env_data_chan, &env_data_lis, K_MSEC(100));
        }
        default: {
            break;
        }
    }

    /* No application-specific behavior is required. Call default signal handler. */
    ZB_ERROR_CHECK(zigbee_default_signal_handler(bufid));

    /* All callbacks should either reuse or free passed buffers. */
    /* If bufid == 0, the buffer is invalid (not passed). */
    if (bufid) {
        zb_buf_free(bufid);
    }
}

void zbus_on_light_callback(const struct zbus_channel *chan)
{
    const struct light_event *evt = zbus_chan_const_msg(chan);

    /* Compute ZCL-scaled value; clamp 0 lux per spec */
    /* See chapter 4.2.2.2.1 if the ZCL Specification */
    zb_uint16_t measured = (evt->light == 0)
                           ? 0
                           : (zb_uint16_t)(10000 * log10((double)evt->light) + 1);

    /* Only update when values differ */
    if (measured == dev_ctx.illuminance_attr.measurement_attr) {
        return;
    }

    dev_ctx.illuminance_attr.measurement_attr = measured;

    if (evt->light > dev_ctx.illuminance_attr.max_attr) {
        dev_ctx.illuminance_attr.max_attr = dev_ctx.illuminance_attr.measurement_attr;
    } else if (evt->light < dev_ctx.illuminance_attr.min_attr) {
        dev_ctx.illuminance_attr.min_attr = dev_ctx.illuminance_attr.measurement_attr;
    }

    LOG_DBG("Light value: %u", dev_ctx.illuminance_attr.measurement_attr);
    LOG_DBG("Light min: %u", dev_ctx.illuminance_attr.min_attr);
    LOG_DBG("Light max: %u", dev_ctx.illuminance_attr.max_attr);

    ZB_ZCL_SET_ATTRIBUTE(
        BEELIGHT_ENDPOINT,
        ZB_ZCL_CLUSTER_ID_ILLUMINANCE_MEASUREMENT,
        ZB_ZCL_CLUSTER_SERVER_ROLE,
        ZB_ZCL_ATTR_ILLUMINANCE_MEASUREMENT_MEASURED_VALUE_ID,
        (zb_uint8_t *)&dev_ctx.illuminance_attr.measurement_attr,
        ZB_FALSE
    );

    ZB_ZCL_SET_ATTRIBUTE(
        BEELIGHT_ENDPOINT,
        ZB_ZCL_CLUSTER_ID_ILLUMINANCE_MEASUREMENT,
        ZB_ZCL_CLUSTER_SERVER_ROLE,
        ZB_ZCL_ATTR_ILLUMINANCE_MEASUREMENT_MIN_MEASURED_VALUE_ID,
        (zb_uint8_t *)&dev_ctx.illuminance_attr.min_attr,
        ZB_FALSE
    );

    ZB_ZCL_SET_ATTRIBUTE(
        BEELIGHT_ENDPOINT,
        ZB_ZCL_CLUSTER_ID_ILLUMINANCE_MEASUREMENT,
        ZB_ZCL_CLUSTER_SERVER_ROLE,
        ZB_ZCL_ATTR_ILLUMINANCE_MEASUREMENT_MAX_MEASURED_VALUE_ID,
        (zb_uint8_t *)&dev_ctx.illuminance_attr.max_attr,
        ZB_FALSE
    );
}

static void zbus_on_env_callback(const struct zbus_channel *chan)
{
    const struct env_event *evt = zbus_chan_const_msg(chan);

    /* Only update when values differ */
    if ((evt->temperature * 100) != dev_ctx.temperature_attr.measurement_attr) {
        /* See chapter 4.4.2.2.1 if the ZCL Specification */
        dev_ctx.temperature_attr.measurement_attr = (zb_uint16_t)(evt->temperature * 100);

        // TODO: Add Min / Max

        ZB_ZCL_SET_ATTRIBUTE(
            BEELIGHT_ENDPOINT,
            ZB_ZCL_CLUSTER_ID_TEMP_MEASUREMENT,
            ZB_ZCL_CLUSTER_SERVER_ROLE,
            ZB_ZCL_ATTR_TEMP_MEASUREMENT_VALUE_ID,
            (zb_uint8_t *)&dev_ctx.temperature_attr.measurement_attr,
            ZB_FALSE
        );

        LOG_DBG("Temperature: %u", dev_ctx.temperature_attr.measurement_attr);
    }

    if ((evt->pressure / 100) != dev_ctx.pressure_attr.measurement_attr) {
        /* See chapter 4.5.2.2.1 if the ZCL Specification */
        dev_ctx.pressure_attr.measurement_attr = (zb_uint16_t)(evt->pressure / 100);

        // TODO: Add Min / Max

        ZB_ZCL_SET_ATTRIBUTE(
            BEELIGHT_ENDPOINT,
            ZB_ZCL_CLUSTER_ID_PRESSURE_MEASUREMENT,
            ZB_ZCL_CLUSTER_SERVER_ROLE,
            ZB_ZCL_ATTR_PRESSURE_MEASUREMENT_VALUE_ID,
            (zb_uint8_t *)&dev_ctx.pressure_attr.measurement_attr,
            ZB_FALSE
        );

        LOG_DBG("Pressure: %u", dev_ctx.pressure_attr.measurement_attr);
    }

    if ((evt->humidity * 100) != dev_ctx.humidity_attr.measurement_attr) {
        /* See chapter 4.7.2.1.1 if the ZCL Specification */
        dev_ctx.humidity_attr.measurement_attr = (zb_uint16_t)(evt->humidity * 100);

        // TODO: Add Min / Max

        ZB_ZCL_SET_ATTRIBUTE(
            BEELIGHT_ENDPOINT,
            ZB_ZCL_CLUSTER_ID_REL_HUMIDITY_MEASUREMENT,
            ZB_ZCL_CLUSTER_SERVER_ROLE,
            ZB_ZCL_ATTR_REL_HUMIDITY_MEASUREMENT_VALUE_ID,
            (zb_uint8_t *)&dev_ctx.humidity_attr.measurement_attr,
            ZB_FALSE
        );

        LOG_DBG("Humidity: %u", dev_ctx.humidity_attr.measurement_attr);
    }

#if CONFIG_BME68X_IAQ
    /* TODO: Add tolerance */
    if ((evt->co2.value != dev_ctx.co2_attr.measurement_attr)) {
        dev_ctx.co2_attr.measurement_attr = (zb_uint16_t)evt->co2.value;
        dev_ctx.co2_attr.tolerance = (zb_uint8_t)evt->co2.tolerance;

        ZB_ZCL_SET_ATTRIBUTE(
            BEELIGHT_ENDPOINT,
            ZB_BEELIGHT_CLUSTER_ID_CO2_MEASUREMENT,
            ZB_ZCL_CLUSTER_SERVER_ROLE,
            ZB_BEELIGHT_ATTR_CO2_MEASUREMENT_VALUE_ID,
            (zb_uint8_t *)&dev_ctx.co2_attr.measurement_attr,
            ZB_TRUE
        );

        LOG_DBG("CO2: %u", dev_ctx.co2_attr.measurement_attr);
    }

    /* TODO: Add tolerance */
    if ((evt->iaq.value != dev_ctx.iaq_attr.measurement_attr)) {
        dev_ctx.iaq_attr.measurement_attr = (zb_uint16_t)evt->iaq.value;
        dev_ctx.iaq_attr.tolerance = (zb_uint8_t)evt->iaq.tolerance;

        ZB_ZCL_SET_ATTRIBUTE(
            BEELIGHT_ENDPOINT,
            ZB_BEELIGHT_CLUSTER_ID_IAQ_MEASUREMENT,
            ZB_ZCL_CLUSTER_SERVER_ROLE,
            ZB_BEELIGHT_ATTR_IAQ_MEASUREMENT_VALUE_ID,
            (zb_uint8_t *)&dev_ctx.iaq_attr.measurement_attr,
            ZB_TRUE
        );

        LOG_DBG("IAQ: %u", dev_ctx.iaq_attr.measurement_attr);
    }

    /* TODO: Add tolerance */
    if ((evt->voc.value != dev_ctx.voc_attr.measurement_attr)) {
        dev_ctx.voc_attr.measurement_attr = (zb_uint16_t)evt->voc.value;
        dev_ctx.voc_attr.tolerance = (zb_uint8_t)evt->voc.tolerance;

        ZB_ZCL_SET_ATTRIBUTE(
            BEELIGHT_ENDPOINT,
            ZB_BEELIGHT_CLUSTER_ID_VOC_MEASUREMENT,
            ZB_ZCL_CLUSTER_SERVER_ROLE,
            ZB_BEELIGHT_ATTR_VOC_MEASUREMENT_VALUE_ID,
            (zb_uint8_t *)&dev_ctx.voc_attr.measurement_attr,
            ZB_TRUE
        );

        LOG_DBG("VOC: %u", dev_ctx.voc_attr.measurement_attr);
    }
#endif /* CONFIG_BME68X_IAQ */
}
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
int main(void)
{
    dk_leds_init();
    dk_buttons_init(on_button_changed_handler);

    register_factory_reset_button(FACTORY_RESET_BUTTON);

    zb_set_ed_timeout(ED_AGING_TIMEOUT_64MIN);
    zb_set_keepalive_timeout(ZB_MILLISECONDS_TO_BEACON_INTERVAL(1 * 60 * 1000));
    zb_zdo_pim_set_long_poll_interval(ZB_MILLISECONDS_TO_BEACON_INTERVAL(10 * 60 * 1000));

#ifdef CONFIG_ZIGBEE_FOTA
#error "Not supported yet!"
    /* Initialize Zigbee FOTA download service */
    zigbee_fota_init(on_zcl_ota_evt_handler);

    /* Mark the current firmware as valid */
    confirm_image();

    /* Register callback for handling ZCL commands */
    ZB_ZCL_REGISTER_DEVICE_CB(on_zcl_cb_handler);
#endif /* CONFIG_ZIGBEE_FOTA */

    /* Register device context (endpoints) */
    ZB_AF_REGISTER_DEVICE_CTX(&env_sensor_ctx);

    app_clusters_attr_init();

    /* Register handler to identify notifications */
    ZB_AF_SET_IDENTIFY_NOTIFICATION_HANDLER(BEELIGHT_ENDPOINT, on_Identify_Handler);

    /* Power off unused sections of RAM to lower device power consumption */
    zb_set_rx_on_when_idle(ZB_FALSE);
    if (IS_ENABLED(CONFIG_RAM_POWER_DOWN_LIBRARY)) {
        power_down_unused_ram();
    }

    /* Start Zigbee default thread */
    zigbee_enable();

    LOG_INF("BeeLight application started");

#if CONFIG_BME68X_IAQ
    LOG_INF("BME68X IAQ support enabled - ensure that the sensor is connected and configured correctly");
#endif

#if CONFIG_APDS9306
    LOG_INF("APDS9306 support enabled - ensure that the sensor is connected and configured correctly");
#endif

    /* Put the MCU into power down mode */
    while (1) {
        k_sleep(K_FOREVER);
    }

    return 0;
}

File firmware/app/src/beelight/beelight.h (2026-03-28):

/*
 * This file is part of the BeeLight project <https://github.com/Kampi/BeeLight>.
 * Copyright (c) 2026 Daniel Kampert.
 *
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
 * You should have received a copy of the GNU General Public License
 * along with this program. If not, see <http://www.gnu.org/licenses/>.
 */

#pragma once

/* Version of the application software (1 byte). */
#define INIT_BASIC_APP_VERSION                  1

/* Version of the implementation of the Zigbee stack (1 byte). */
#define INIT_BASIC_STACK_VERSION                10

/* Version of the hardware of the device (1 byte). */
#define INIT_BASIC_HW_VERSION                   1

/* Manufacturer name (32 bytes). */
#define INIT_BASIC_MANUF_NAME                   "Kampi"

/* Model number assigned by manufacturer (32-bytes long string). */
#define INIT_BASIC_MODEL_ID                     "BeeLight_v2"

/* First 8 bytes specify the date of manufacturer of the device
 * in ISO 8601 format (YYYYMMDD). The rest (8 bytes) are manufacturer specific.
 */
#ifdef CONFIG_DEBUG
#define INIT_BASIC_DATE_CODE                    "20251019_Debug"
#else
#define INIT_BASIC_DATE_CODE                    "20251019_Release"
#endif

/* Describes the physical location of the device (16 bytes).
 * May be modified during commissioning process.
 */
#define INIT_BASIC_LOCATION_DESC                "Office desk"

/* Button used to enter the Identify mode. */
#define IDENTIFY_MODE_BUTTON                    DK_BTN1_MSK

/* LED indicating that light switch successfully joined Zigbee network. */
#define ZIGBEE_NETWORK_STATE_LED                DK_LED1

/* Button to start Factory Reset. */
#define FACTORY_RESET_BUTTON                    IDENTIFY_MODE_BUTTON

/* Define 'bat_num' as empty in order to declare default battery set attributes. */
/* According to Table 3-17 of ZCL specification, defining 'bat_num' as 2 or 3 allows */
/* to declare battery set attributes for BATTERY2 and BATTERY3. */
#define bat_num

/** @brief Device endpoint, used to receive environment sensor results.
 */
#define BEELIGHT_ENDPOINT                       10

/** @brief The rated battery voltage in millivolts.
 */
#define BEELIGHT_RATED_VOLTAGE_MV               3300UL

/** @brief The lowest battery voltage in millivolts.
 */
#define BEELIGHT_EMPTY_VOLTAGE_MV               2700UL

/** @brief ZigBee device version.
*/
#define ZB_DEVICE_VER                           1

/** @brief  ZigBee profile ID used
 *          See ZIGBEE HOME AUTOMATION PUBLIC APPLICATION PROFILE table 5.1 for additional information.
*/
#define ZB_PROFILE_ID                           ZB_AF_HA_PROFILE_ID

/** @brief  ZigBee device ID
 *          See ZIGBEE HOME AUTOMATION PUBLIC APPLICATION PROFILE table 5.1 for additional information.
*/
#define ZB_DEVICE_ID                            0x106

/** @brief                  Declare endpoint for the Environment Sensor device.
 *  @param ep_name          Endpoint variable name
 *  @param ep_id            Endpoint ID
 *  @param cluster_list     Endpoint cluster list
 */
#define BEELIGHT_DECLARE_EP(ep_name, ep_id, cluster_list)                       \
    BEELIGHT_DECLARE_SIMPLE_DESC(                                               \
        ep_name,                                                                \
        ep_id,                                                                  \
        BEELIGHT_IN_CLUSTER_NUM,                                                \
        BEELIGHT_OUT_CLUSTER_NUM                                                \
    );                                                                          \
    ZBOSS_DEVICE_DECLARE_REPORTING_CTX(                                         \
        reporting_info##ep_name,                                                \
        BEELIGHT_REPORT_ATTR_COUNT                                              \
    );                                                                          \
    ZB_AF_DECLARE_ENDPOINT_DESC(                                                \
        ep_name,                                                                \
        ep_id,                                                                  \
        ZB_PROFILE_ID,                                                          \
        0,                                                                      \
        NULL,                                                                   \
        ZB_ZCL_ARRAY_SIZE(cluster_list, zb_zcl_cluster_desc_t),                 \
        cluster_list,                                                           \
        (zb_af_simple_desc_1_1_t *)&simple_desc_##ep_name,                      \
        BEELIGHT_REPORT_ATTR_COUNT,                                             \
        reporting_info##ep_name,                                                \
        0,                                                                      \
        NULL                                                                    \
    )

/** @brief 3.3 Power Attributes
*/
typedef struct {
    zb_uint8_t voltage;                 /**< Attribute 3.3.2.2.3.1 */
    zb_uint8_t size;                    /**< Attribute 3.3.2.2.4.2 */
    zb_uint8_t quantity;                /**< Attribute 3.3.2.2.4.4 */
    zb_uint8_t rated_voltage;           /**< Attribute 3.3.2.2.4.5 */
    zb_uint8_t alarm_mask;              /**< Attribute 3.3.2.2.4.6 */
    zb_uint8_t voltage_min_threshold;   /**< Attribute 3.3.2.2.4.7 */
    zb_uint8_t percent_remaining;       /**< Attribute 3.3.2.2.3.1
                                             NOTE: A value of 200  is equal to 100%! */
    zb_uint8_t voltage_threshold_1;     /**< Attribute 3.3.2.2.4.8 */
    zb_uint8_t voltage_threshold_2;     /**< Attribute 3.3.2.2.4.8 */
    zb_uint8_t voltage_threshold_3;     /**< Attribute 3.3.2.2.4.8 */
    zb_uint8_t percent_min_threshold;   /**< Attribute 3.3.2.2.4.9 */
    zb_uint8_t percent_threshold_1;     /**< Attribute 3.3.2.2.4.10 */
    zb_uint8_t percent_threshold_2;     /**< Attribute 3.3.2.2.4.10 */
    zb_uint8_t percent_threshold_3;     /**< Attribute 3.3.2.2.4.10 */
    zb_uint32_t alarm_state;            /**< Attribute 3.3.2.2.4.11 */
} zb_zcl_power_attrs_t;

/** @brief 4.2 Illuminance Measurement
*/
typedef struct {
    zb_uint16_t measurement_attr;       /**< Attribute 4.2.2.2.1 */
    zb_uint16_t min_attr;               /**< Attribute 4.2.2.2.2 */
    zb_uint16_t max_attr;               /**< Attribute 4.2.2.2.3 */
} zb_zcl_illuminance_attrs_t;

/** @brief 4.4 Temperature Measurement
*/
typedef struct {
    zb_uint16_t measurement_attr;       /**< Attribute 4.4.2.2.1 */
    zb_uint16_t min_attr;               /**< Attribute 4.4.2.2.2 */
    zb_uint16_t max_attr;               /**< Attribute 4.4.2.2.3 */
    zb_uint16_t tolerance;              /**< Attribute 4.4.2.2.4 */
} zb_zcl_temperature_attrs_t;
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

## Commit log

2026-03-27 Working on revision 2.0
    Working on revision 2.0
    - Remove old files
    - Replace nRF53 with nRF54L15
    - Update README.md
    - Update converter for z2m
    - Update documentation
    - Fix typos in DTS includes
    - Fix wrong patch command
    - Add BME688
    - Add dimension to PCB specification Kibot output
    - Add blocklist to west.yml
    - Add missing mounting holes
    - Add custom cluster for VOC, IAQ and CO2 for Zigbee2Mqtt
    - Add patches for custom cluster for ncs-zigbee
    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
    [BIVAR__INC_PLP1-188-F.stp, BOM_Mouser.xlsx, BeeLight-(L1-L2)_NPTH_drill_table.csv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]
2026-03-27 Working on revision 2.0
    - Remove log files from artifacts
    - Fix wrong battery conversion
    - Add west command to build and flash the device configuration
    - Add 3D files for the housing
    - Add 3D printer project for the housing
    - Add KiBot template from Vincent
    - Add CI/CD for firmware
    - Add CI/CD pip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
2026-03-27 Issue #40, Issue #42, Issue #45
    [BOM_Mouser.xlsx, BeeLight-(L1-L2)_NPTH_drill_table.csv, BeeLight-(L1-L2)_drill_table.csv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]
2026-03-27 Task: Update documentation
    - Simplify BeeLight headers
    - Add group-filter to west manifest
    - Add commit template
2026-03-27 Firmware: Add AStyle support for west
    [astyle.cfg]
2026-03-27 Device Tree: Fix I2C issues - Remove GPIO I2C from rev 2 device tree - Fix wrong pinctrl references for I2C2
2026-03-27 - Fix wrong KiBot version variables - CI/CD: Add CodeRabbit configuration file - CI/CD: Fix issues reported by CodeRabbit
    [Revision History.kicad_sch]
2026-03-27 Feature: Issue #28
    - Switch from CR2032 to CR2477 batteries for longer runtime
    Closes #28
    [BeeLight.kicad_pcb, Bot v22.stl, Housing.3mf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]
2026-03-27 - Update CHANGELOG - Update README - Add release or debug info to Zigbee FW version - Fixes from CodeRabbit - Simplify the cluster definitions and rename them
    [beelight.h]
2026-03-27 Bug: Issue #48
    - Wrong date variable in PCB CI/CD
    Closes #48
2026-03-27 Update KiBot configuration to the latest version
    [.astyle.cfg, BeeLight.kicad_pcb]
2026-03-27 Push outputs from CI/CD (2026-03-17 20:23:36)
    [BeeLight-(L1-L2)_NPTH_drill_table.csv, BeeLight-(L1-L2)_drill_table.csv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]
2026-03-27 Task: Issue #49
    - Update z2m configuration files to latest format
    Closes #49
    [BeeLight.kicad_pcb]
2026-03-28 Prepare release 2.1
    [.astyle.cfg, BeeLight-(L1-L2)_NPTH_drill_table.csv, BeeLight-(L1-L2)_drill_table.csv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]

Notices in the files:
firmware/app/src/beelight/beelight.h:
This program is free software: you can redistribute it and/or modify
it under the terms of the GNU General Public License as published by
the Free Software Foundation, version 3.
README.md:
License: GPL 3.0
